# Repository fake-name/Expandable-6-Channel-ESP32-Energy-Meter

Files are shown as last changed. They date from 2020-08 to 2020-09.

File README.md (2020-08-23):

Expandable 6 Channel ESP32 Energy Meter v1.3 Main Board

# CircuitSetup Expandable 6 Channel ESP32 Energy Meter
The Expandable 6 Channel ESP32 Energy Meter can read 6 current channels and 2 voltage channels at a time. Much like our [Split Single Phase Energy Meter](https://circuitsetup.us/index.php/product/split-single-phase-real-time-whole-house-energy-meter-v1-4/), the 6 channel uses current transformers and an AC transformer to measure voltage and power the board(s)/ESP32\. The main board includes a buck converter to power the electronics and ESP32 dev board, which plugs directly into the board. Up to 6 add-on boards can stack on top of the main board to allow you to monitor **up to 42 current channels** in 16-bit resolution, in real time, all at once! This product is currently in the prototype stage, so components may change.

#### **Usage:**

* North American split single phase 120V/240V 60Hz - mains and/or individual circuits
* European single phase 240V 50Hz (must provide [AC-AC transformer](https://learn.openenergymonitor.org/electricity-monitoring/voltage-sensing/different-acac-power-adapters) 9V or 12V with at least 500mA output)
* 3 phase - the meter can be used to measure 3-phase, but power (wattage) will not be calculated correctly. Power can be calculated in software, but the [power factor](https://en.wikipedia.org/wiki/Power_factor) will have to be estimated ((voltage*current)*power_factor))

#### **Features:**

*   Samples 6 current channels & 1 voltage channel (expandable to 2 voltage)
*   Add-on boards (up to 6) can expand the meter up to 42 current channels & 8 voltage channels
*   Uses 2 [Microchip ATM90E32AS](https://www.microchip.com/wwwproducts/en/atm90e32as) - 3 current channels & 1 voltage per IC
*   For each channel the following can also be calculated by the meter:
    *   Active Power
    *   Reactive Power
    *   Apparent Power
    *   Power Factor
    *   Frequency
    *   Temperature
*   Uses standard current transformer clamps to sample current
*   22ohm burden resistors per current channel
*   Includes built-in buck converter to power ESP32 & electronics
*   2 IRQ interrupts, and 1 Warning output
*   Zero crossing outputs
*   Energy Pulse outputs per IC (4 per IC x2)
*   SPI Interface
*   Measurement Error: 0.1%
*   Dynamic Range: 6000:1
*   Current Gain Selection: Up to 4x
*   Voltage Reference Drift Typical (ppm/°C): 6
*   ADC Resolution (bits): 16

#### **What you'll need:**

*   **Current Transformers** (any combination of the following, or any current transformer that does not exceed 1V or 720mA output)
    *   [SCT-006 20A/25mA Micro](https://circuitsetup.us/index.php/product/20a-25ma-micro-current-transformer-yhdc-sct-006-6mm/) (6mm opening - 3.5mm connectors)
    *   [SCT-010 80A/26.6mA Mini](https://circuitsetup.us/index.php/product/80a-26-6ma-mini-current-transformer-yhdc-sct-010-10mm/) (10mm opening - 3.5mm connectors)
    *   [SCT-013-000 100A/50mA](https://circuitsetup.us/index.php/product/100a-50ma-current-transformer-yhdc-sct-013/) (13mm opening - 3.5mm connectors)
    *   [SCT-016 120A/40mA](https://circuitsetup.us/index.php/product/120a-40ma-current-transformer-yhdc-sct-016-with-3-5mm-jack-16mm-opening/) (16mm opening - 3.5mm connectors)
    *   [Magnelab SCT-0750-100](https://amzn.to/2IF8xnY) (screw connectors - must sever burden resistor connection on the back of the board since they have a built in burden resistor).
    *   [SCT-024 200A/100mA](https://www.poweruc.pl/products/split-core-current-transformer-sct024ts-rated-input-400a) (24mm opening - terminal output)
    *   Others can also be used as long as they're rated for the amount of power that you are wanting to measure, and have a current output no more than 720mA.
*   **AC Transformer (NOT DC):** 
    *   North America: [Jameco Reliapro 120V to 9V AC-AC](https://circuitsetup.us/index.php/product/jameco-ac-to-ac-wall-adapter-transformer-9-volt-1000ma-black-straight-2-5mm-female-plug/) or 12v. The positive pin must be 2.5mm (some are 2.1)
    *   Europe: 240V to 9V or 12V AC-AC at least 500mA - [See a list of some recommended transformers here](https://learn.openenergymonitor.org/electricity-monitoring/voltage-sensing/different-acac-power-adapters)
*   **ESP32** (choose one):
    *   [NodeMCU 32s](https://circuitsetup.us/index.php/product/nodemcu-32s-esp32-esp-wroom-32-development-board/)
    *   [Espressif DevKitC](https://amzn.to/2PHvVsg)
    *   [DevKitC-32U](https://www.mouser.com/ProductDetail/Espressif-Systems/ESP32-DevKitC-32U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) if you need better wifi reception (don't forget the antenna)
    *   Anything else with the same pinouts as the above, which are usually 19 pins per side with 3v3 in the upper left & CLK in the lower right
*   **Software** (choose one):
    *   Our custom version of [EmonESP](https://github.com/CircuitSetup/Expandable-6-Channel-ESP32-Energy-Meter/tree/master/Software/EmonESP) and the [ATM90E32](https://github.com/CircuitSetup/ATM90E32) Arduino library
    *   The current dev release of [ESPHome.](https://github.com/esphome/esphome/tree/dev) Details on [integration with Home Assistant are located here.](https://github.com/digiblur/digiNRG_ESPHome) and [here on ESPHome.io](https://next.esphome.io/components/sensor/atm90e32.html). [More examples of configs are located here.](https://github.com/CircuitSetup/Expandable-6-Channel-ESP32-Energy-Meter/tree/master/Software/ESPHome)
    *   Libraries for [CircuitPython](https://github.com/BitKnitting/CircuitSetup_CircuitPython) & [MicroPython](https://github.com/BitKnitting/CircuitSetup_micropython)

### **Setting up the Meter**

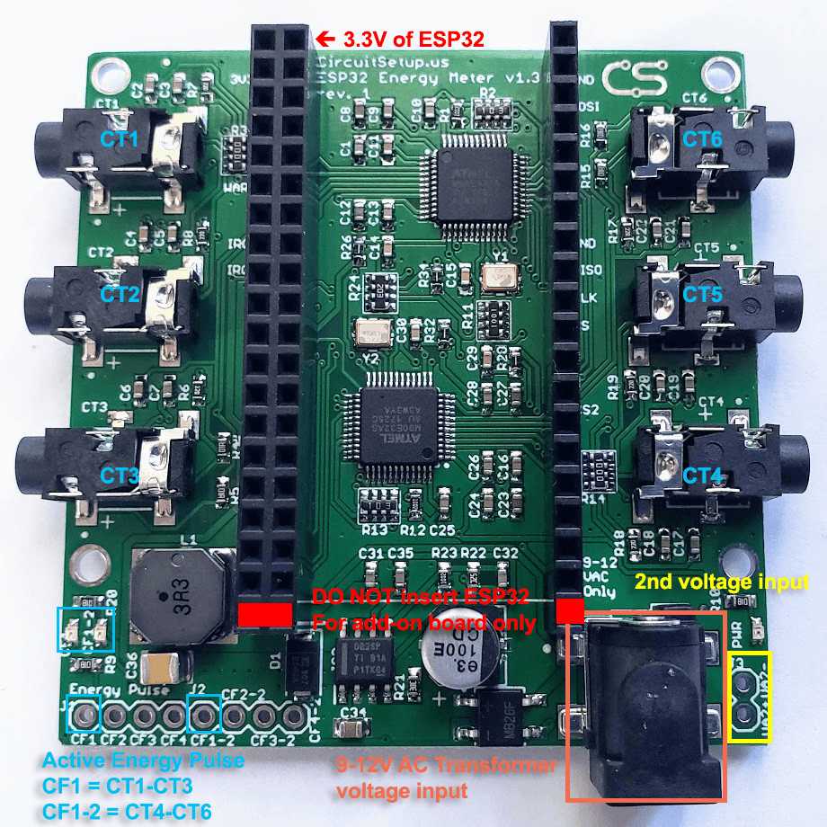
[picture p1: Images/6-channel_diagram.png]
Expandable 6 Channel ESP32 Energy Meter Diagram

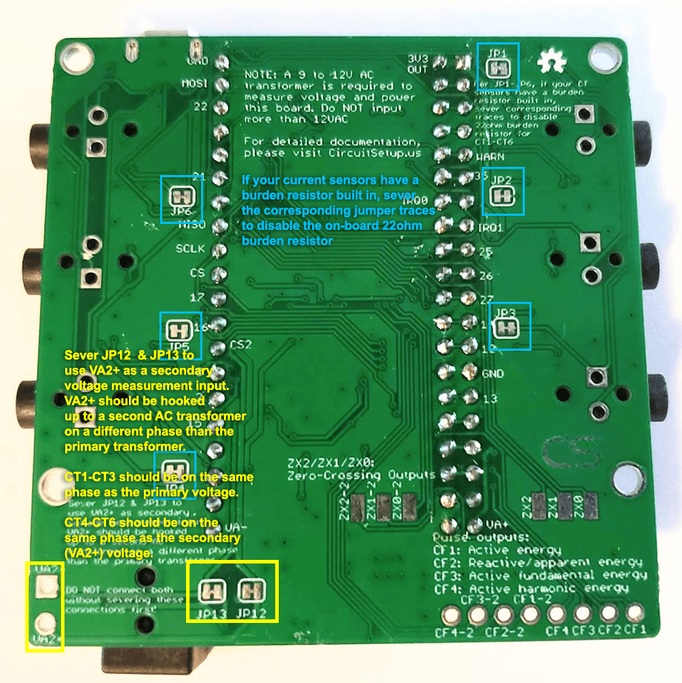
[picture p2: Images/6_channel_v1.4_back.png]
Expandable 6 Channel ESP32 Energy Meter Back Diagram


#### **Plugging in the ESP32**
The Expandable 6 Channel ESP32 Energy Meter is made so that an ESP32 dev board can be plugged directly into the meter. See the list above for compatible ESP32 dev boards. 
**Always insert the ESP32 with the 3V3 pin in the upper left of the meter**. The bottom pins are used to connect the voltage signal (from the power plug) to add-on boards. If the ESP32 is inserted into the bottom pins it will more than likely short the ESP32.

#### **Communicating with the ESP32**
The Expandable 6 Channel ESP32 Energy Meter uses SPI to communicate with the ESP32. Each board uses 2 CS pins. 

The **main board** uses the following SPI pins:
* CLK - 18
* MISO - 19
* MOSI - 23
* CS1 - 5 (CT1-CT3 & Voltage 1)
* CS2 - 4 (CT4-CT6 & Voltage 2)

The version of [EmonESP available here](https://github.com/CircuitSetup/Expandable-6-Channel-ESP32-Energy-Meter/tree/master/Software/EmonESP) has all of these pins set by default. 

For examples of how to set up your config in ESPHome, [see here](https://github.com/CircuitSetup/Expandable-6-Channel-ESP32-Energy-Meter/tree/master/Software/ESPHome) and [here.](https://next.esphome.io/components/sensor/atm90e32.html)

#### **Add-on Boards**
Add-on boards (up to 6) can expand the main energy meter up to 42 current channels & 8 voltage channels. The add-on boards plug directly into the main board as seen here.

The **add-on board** allows the CS pin to be selected based on the jumper settings at the bottom of the board. This is so multiple add-on boards can be used - up to 6 maximum. Do NOT select more than one CS pin per bank. 
The CS pins can be:
  * CT1-CT3 (CS):
    * For v1.3 and under:
      * 0
      * 2 (*make sure that an on board LED is not used for IO2 on the ESP32) 
      * 12 (*will cause ESP32 to not boot if used)
      * 13
      * 14
      * 15
    * For v1.4 and above:
      * 0
      * 27
      * 35 (do not use - it will not work correctly)
      * 13
      * 14
      * 15
    * For v1.4 rev1 and above:
      * 35 is changed to 2 (may prevent the ESP32 from being programmed - disconnect jumper if so)
  * CT4-CT6 (CS2):
    * 16
    * 17
    * 21
    * 22
    * 25
    * 26
    
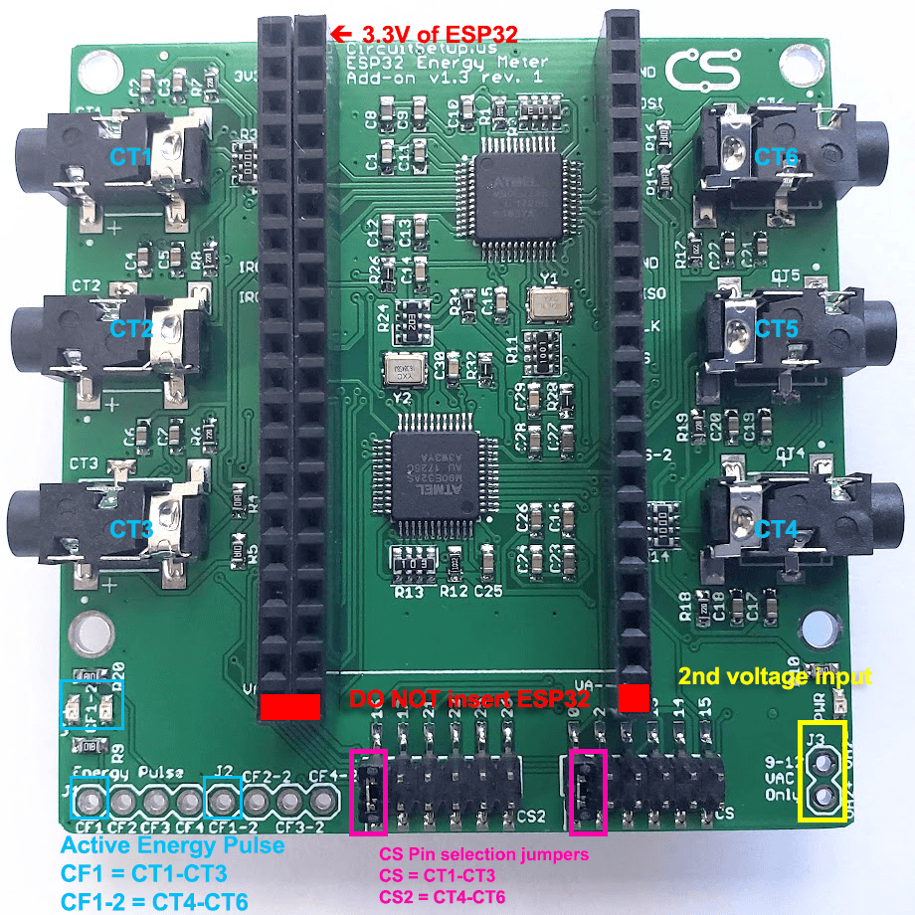
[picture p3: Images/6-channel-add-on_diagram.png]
Expandable 6 Channel ESP32 Energy Meter Add-on Diagram


#### **Calibrating Current Sensors & Voltage (AC Transformer)** 
[See here for the calibration procedure](https://github.com/CircuitSetup/Split-Single-Phase-Energy-Meter#calibration),
[or here for a video](https://youtu.be/BOgy6QbfeZk?t=1261)

##### **Common Calibration Values**
 * Current Transformers:
    * 20A/25mA SCT-006: 11143
    * 30A/1V SCT-013-030: 8650
    * 50A/1V SCT-013-050: 15420
    * 80A/26.6mA SCT-010: 41660
    * 100A/50ma SCT-013-000: 27518
    * 120A/40mA: SCT-016: 41787
    * 200A/100mA SCT-024: 27518
* AC Transformers
    * Jameco 9VAC Transformer 157041: 
       * For meter versions: 
         * v1.3 or greater: 7305
         * v1.2: 42620

#### **Measuring Power & Other Metering Values**
The Expandable 6 Channel ESP32 Energy Meter uses 2 ATM90E32AS ICs. Each IC has 3 voltage channels and 3 current channels. In order for power metering data to be calculated internally, each current channel must have a reference voltage. If the voltage is out of phase with the current, then the current and power will read as negative, affecting the power factor and power calculations. If you have a split single phase or dual phase setup, the solution is to turn around the current transformer on the wire.

v1.1 of the meter used 1 of the voltage channels for each IC. This means that power and metering data would have to be calculated in software, or voltage channels would have to be mapped via changing registers on the IC to get power and metering data from CT2, CT3, CT5, CT6. 

v1.2 & v1.3 have JP8-JP11 on the back of the board, that would allow all voltage channels to be connected together, which would allow power and other metering values to be calculated. Most of v1.3 came soldered together.

v1.4 removed JP8-JP11, and has voltage channels connected internally on the pcb. 

#### **Measuring A Second Voltage**
The holes labelled VA2 next to the power plug on the meter main board, and in the bottom right of the add-on board are for measuring a second voltage. To do this you must:
* Sever (with a knife) JP12 and JP13 on the back of the board for v1.3+, or JP7 for prior versions
* Use a second AC transformer, ideally one identical to the primary
* Plug in the second AC transformer to an outlet on the opposite phase to the primary
* Solder on a pin header, 2.54mm screw connector, or pigtail on to VA2+ & VA2-

When voltage jumpers are severed, the voltage reference for CT4-CT6 will be from VA2. This means that current transformers for CT4-CT6 should be hooked up to circuits that are on the same phase as VA2, and CT1-CT3 should be hooked up to circuits that are in phase with the primary voltage. If a CT is not in phase with the voltage its current and power readings will be negative. If, for example, you have 4 circuits in phase with the primary, and 2 in phase with VA2, you can reverse the current transformer on the wire to put it in phase with the voltage. 

For add-on boards, the primary voltage will come from the main board. The optional secondary voltage measurement (also VA2 pins), will be in phase with CT4-CT6.

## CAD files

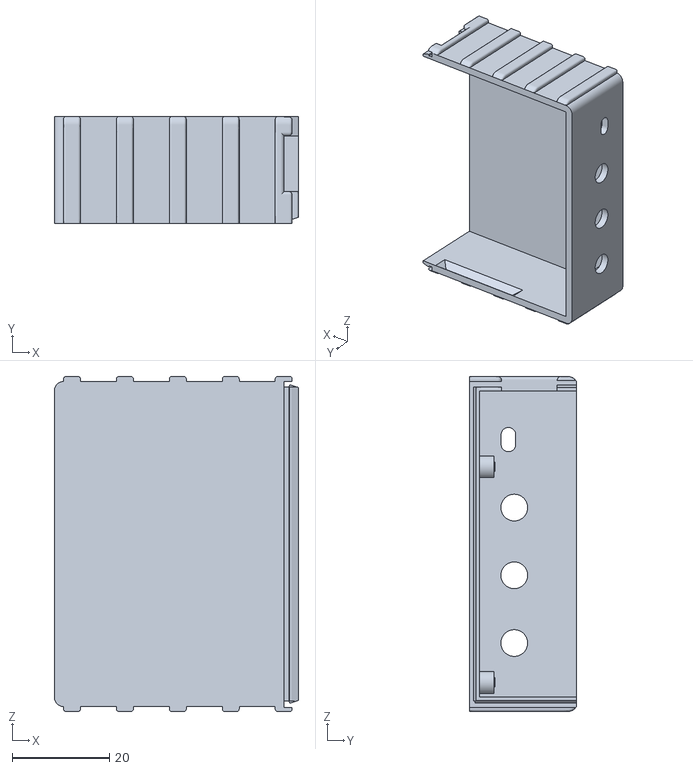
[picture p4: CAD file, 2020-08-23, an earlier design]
Hardware/Eagle-Old/6channel_energy_meter_2piece_case_main_board_large_half.stl
50.3 x 22.0 x 69.0

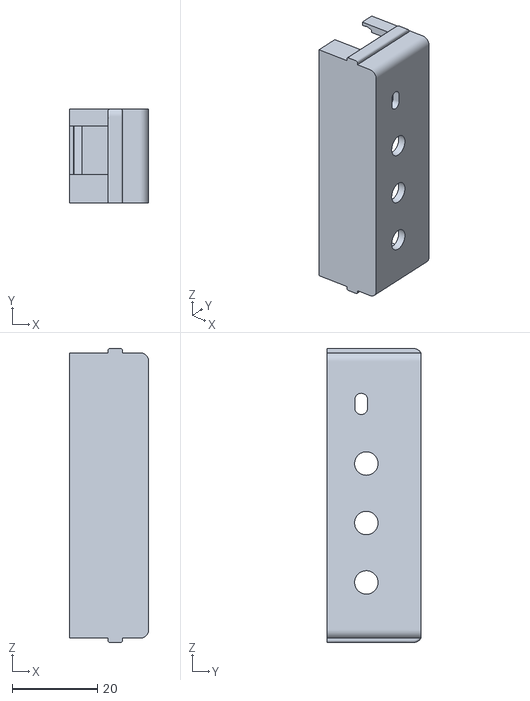
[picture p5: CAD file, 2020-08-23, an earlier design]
Hardware/Eagle-Old/6channel_energy_meter_2piece_case_main_board_small_half.stl
18.6 x 22.0 x 69.0

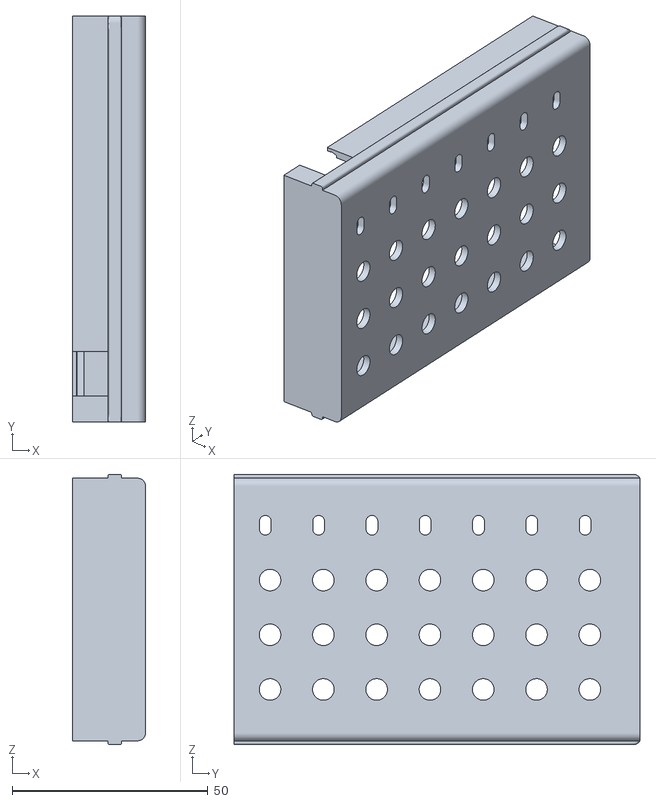
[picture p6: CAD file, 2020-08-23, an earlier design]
Hardware/Eagle-Old/6channel_energy_meter_2piece_case_6-addon_small_half.stl
18.6 x 103.6 x 69.0

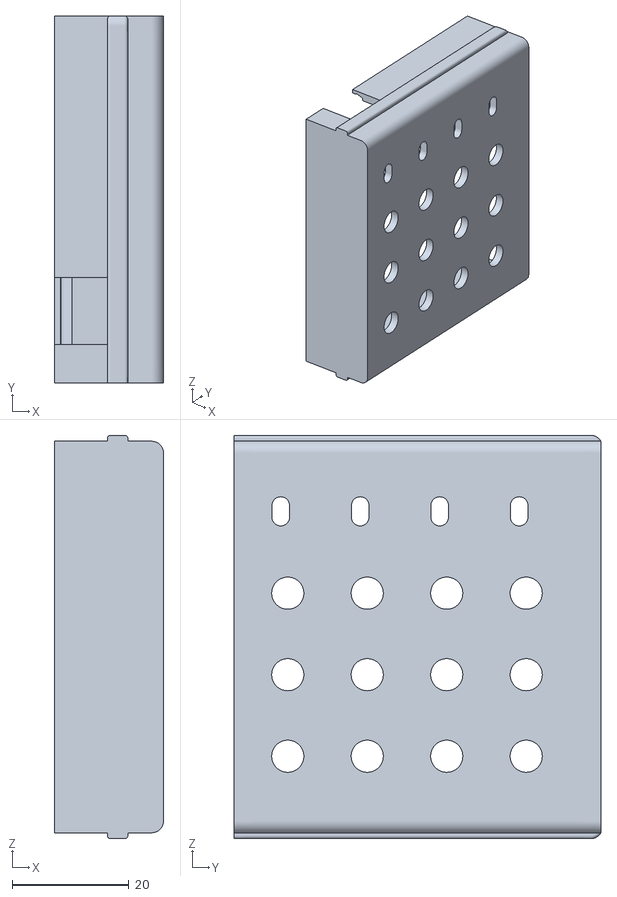
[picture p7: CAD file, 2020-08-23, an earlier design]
Hardware/Eagle-Old/6channel_energy_meter_2piece_case_3-addon_small_half.stl
18.6 x 62.8 x 69.0

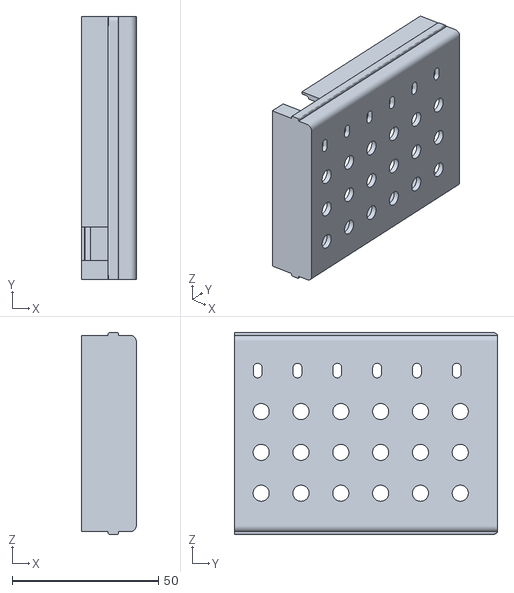
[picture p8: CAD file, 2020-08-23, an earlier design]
Hardware/Eagle-Old/6channel_energy_meter_2piece_case_5-addon_small_half.stl
18.6 x 90.0 x 69.0

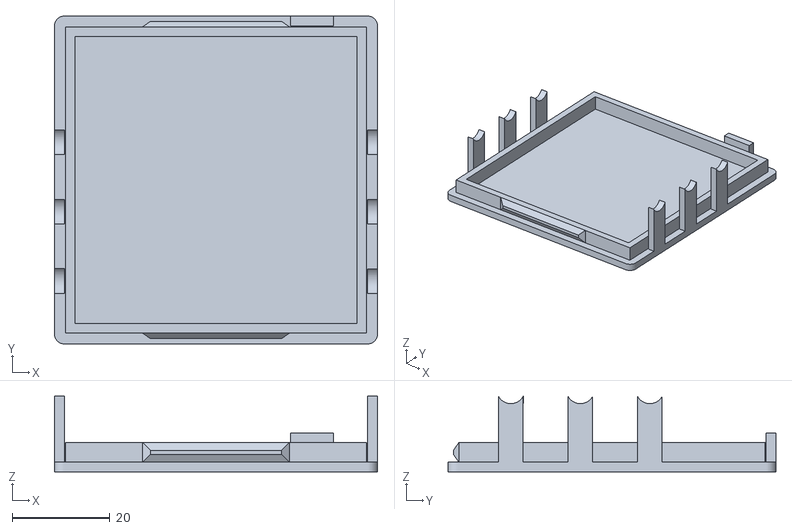
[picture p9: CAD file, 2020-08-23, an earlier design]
Hardware/Eagle-Old/6channel_case_lid.stl
66.0 x 67.0 x 15.5

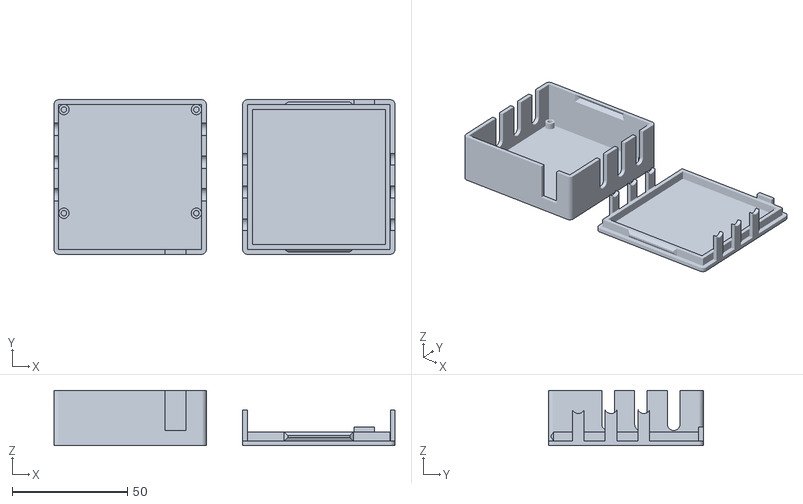
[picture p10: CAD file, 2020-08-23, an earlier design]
Hardware/Eagle-Old/6channel_meter_case.stl
147.7 x 67.0 x 24.0

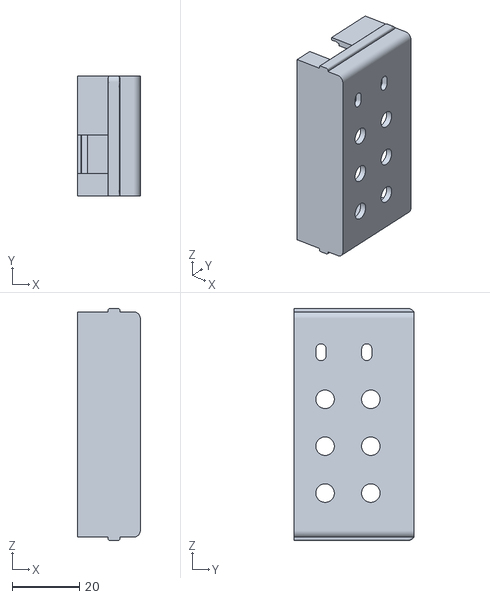
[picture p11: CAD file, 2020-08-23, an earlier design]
Hardware/Eagle-Old/6channel_energy_meter_2piece_case_1-addon_small_half.stl
18.6 x 35.6 x 69.0

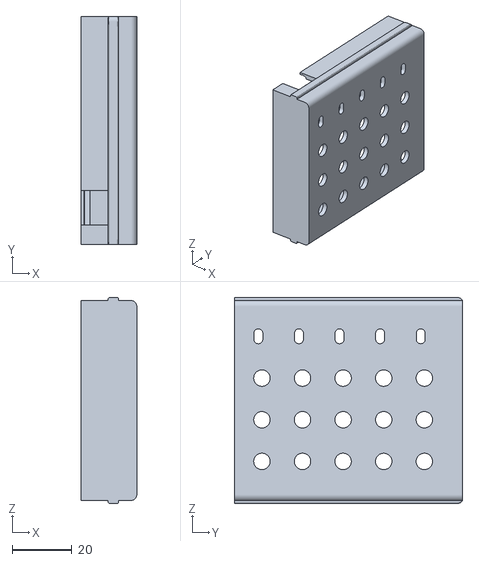
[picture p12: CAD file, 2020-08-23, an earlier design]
Hardware/Eagle-Old/6channel_energy_meter_2piece_case_4-addon_small_half.stl
18.6 x 76.4 x 69.0

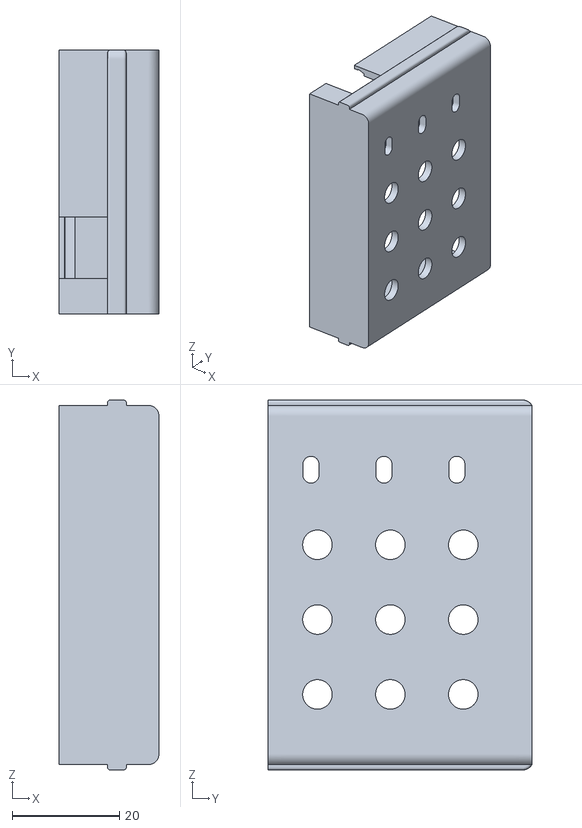
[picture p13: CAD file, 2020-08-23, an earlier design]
Hardware/Eagle-Old/6channel_energy_meter_2piece_case_2-addon_small_half.stl
18.6 x 49.2 x 69.0

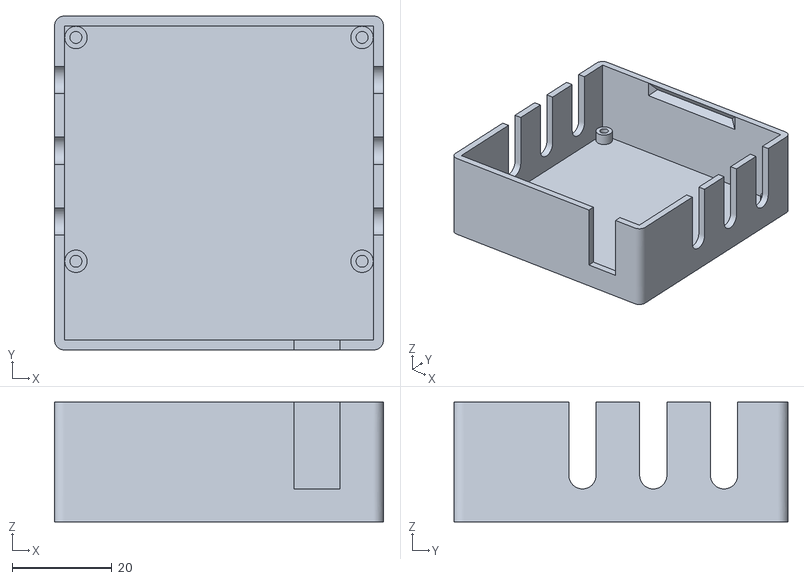
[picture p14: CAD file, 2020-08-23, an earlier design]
Hardware/Eagle-Old/6channel_case.stl
66.0 x 67.0 x 24.0

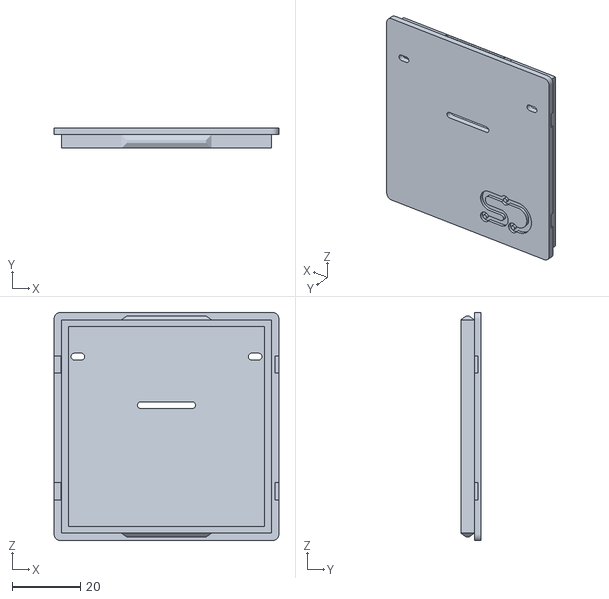
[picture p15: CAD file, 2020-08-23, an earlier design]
Hardware/Eagle-Old/6channel_energy_meter_2piece_case_cover.stl
66.0 x 6.00 x 67.0

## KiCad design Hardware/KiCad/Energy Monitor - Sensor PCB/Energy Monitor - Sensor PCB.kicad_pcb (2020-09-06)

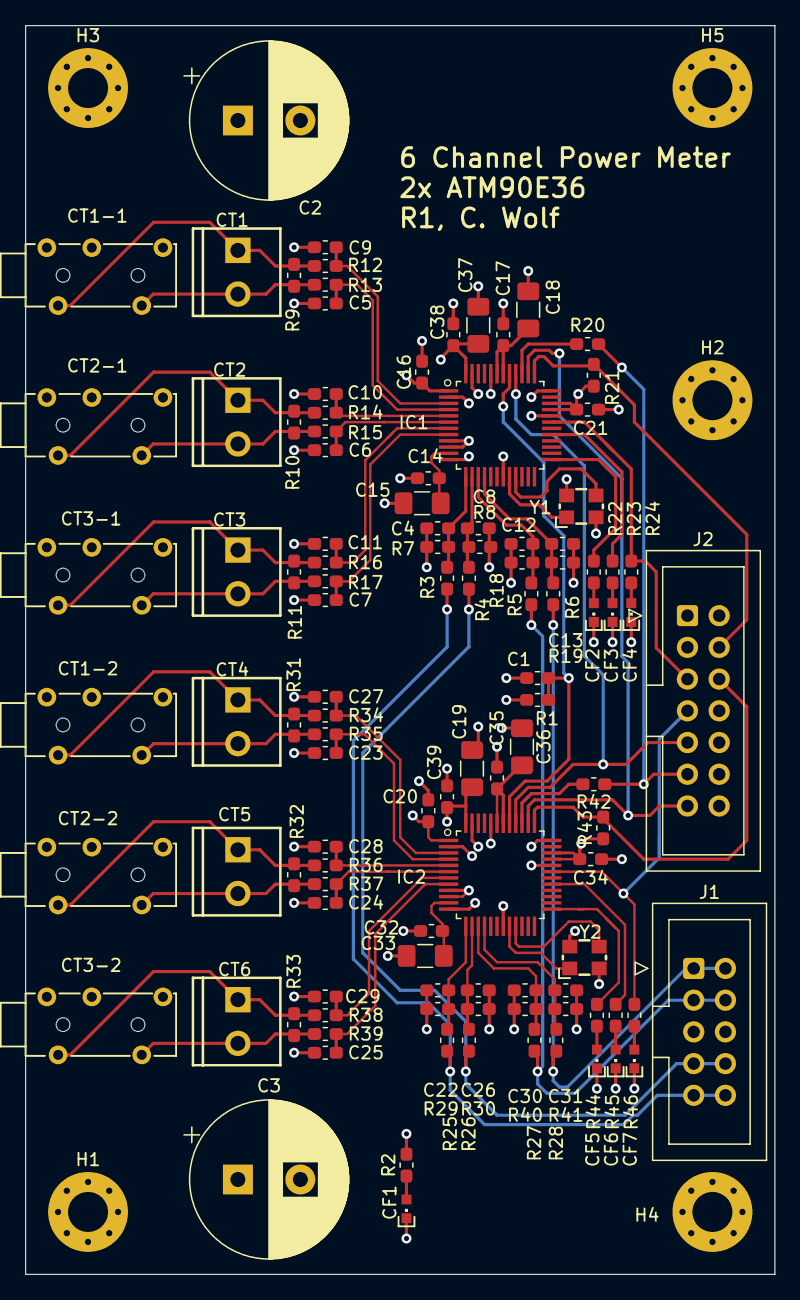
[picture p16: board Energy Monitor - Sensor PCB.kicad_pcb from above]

Board: 4 copper layers, 60.0 x 100.0 mm, 115 parts (0 on the bottom side), 67 nets.

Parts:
C1, C14, C16, C17, C20, C21, C32, C34, C35, C38, C39: 0.1uF; C_0603_1608Metric_Pad1.05x0.95mm_HandSolder
C2, C3: CP1; CP_Radial_D12.5mm_P5.00mm
C4, C8, C12, C13, C22, C26, C30, C31: 18nF; C_0603_1608Metric_Pad1.05x0.95mm_HandSolder
C5, C6, C7, C9, C10, C11, C23, C24, C25, C27, C28, C29: 0.33uF; C_0603_1608Metric_Pad1.05x0.95mm_HandSolder
C15, C18, C19, C33, C36, C37: 10uF; C_1206_3216Metric_Pad1.42x1.75mm_HandSolder
CF1, CF2, CF3, CF4, CF5, CF6, CF7: BLU; CHIPLED_0603
CT1, CT2, CT3, CT4, CT5, CT6: CONN_023.5MM; SCREWTERMINAL-3.5MM-2
CT1-1, CT1-2, CT2-1, CT2-2, CT3-1, CT3-2: SJ2-35813B-SMT-TR; PJ-3270
H1, H2, H3, H4, H5: MountingHole; MountingHole_3.2mm_M3_Pad_Via
IC1, IC2: ATM90E36; QFP50P900X900X120-48
J1: Conn_02x05_Odd_Even; IDC-Header_2x05_P2.54mm_Vertical
J2: Conn_02x07_Odd_Even; IDC-Header_2x07_P2.54mm_Vertical
R1, R21, R43: 10K; R_0603_1608Metric_Pad1.05x0.95mm_HandSolder
R2: 1k; R_0603_1608Metric_Pad1.05x0.95mm_HandSolder
R3, R4, R5, R6, R25, R26, R27, R28: 20K; R_0603_1608Metric_Pad1.05x0.95mm_HandSolder
R7, R8, R18, R19, R22, R23, R24, R29, R30, R40, R41, R44, R45, R46: 1K; R_0603_1608Metric_Pad1.05x0.95mm_HandSolder
R9, R10, R11, R31, R32, R33: 22R; R_0603_1608Metric_Pad1.05x0.95mm_HandSolder
R12, R13, R14, R15, R16, R17, R20, R34, R35, R36, R37, R38, R39, R42: 100R; R_0603_1608Metric_Pad1.05x0.95mm_HandSolder
Y1, Y2: 16.384MHz; CRYSTAL-SMD-3.2X2.5MM

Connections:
+3V3: C2.1, C3.1, C16.1, C19.1, C20.1, C21.1, C34.1, C37.1, C38.1, C39.1, IC1.1, IC1.33, IC1.34, IC1.48, IC2.1, IC2.33, IC2.34, IC2.48, J2.1, J2.3, R1.1, R2.2, R21.1, R43.1
/meter_1/1.8VDD: C17.1, C18.1, IC1.42, IC1.43
/meter_1/I1N: C5.1, IC1.4, R13.2
/meter_1/I1P: C9.1, IC1.3, R12.2
/meter_1/I2N: C6.1, IC1.6, R15.2
/meter_1/I2P: C10.1, IC1.5, R14.2
/meter_1/I3N: C7.1, IC1.8, R17.2
/meter_1/I3P: C11.1, IC1.7, R16.2
/meter_1/IRQ1: IC1.31, J2.5, R24.1
/meter_1/SCLK: IC1.38, IC2.38, J2.13
/meter_1/SDI: IC1.40, IC2.40, J2.9
/meter_1/SDO: J2.11, R20.1, R42.1
/meter_1/V1N: J1.7, J1.8, R4.2, R26.2
/meter_1/V1P: J1.9, J1.10, R3.2, R25.2
/meter_1/V2N: J1.1, J1.2, R6.2, R28.2
/meter_1/V2P: J1.3, J1.4, R5.2, R27.2
/meter_1/~CS: IC1.37, J2.4, R21.2
/meter_1/~RESET: C1.1, IC1.41, IC2.41, R1.2
/meter_2/1.8VDD: C35.1, C36.1, IC2.42, IC2.43
/meter_2/I1N: C23.1, IC2.4, R35.2
/meter_2/I1P: C27.1, IC2.3, R34.2
/meter_2/I2N: C24.1, IC2.6, R37.2
/meter_2/I2P: C28.1, IC2.5, R36.2
/meter_2/I3N: C25.1, IC2.8, R39.2
/meter_2/I3P: C29.1, IC2.7, R38.2
/meter_2/IRQ1: IC2.31, J2.7, R46.1
/meter_2/~CS: IC2.37, J2.6, R43.2
GND: C1.2, C2.2, C3.2, C4.2, C5.2, C6.2, C7.2, C8.2, C9.2, C10.2, C11.2, C12.2, C13.2, C14.2, C15.2, C16.2, C17.2, C18.2, C19.2, C20.2, C21.2, C22.2, C23.2, C24.2, C25.2, C26.2, C27.2, C28.2, C29.2, C30.2, C31.2, C32.2, C33.2, C34.2, C35.2, C36.2, C37.2, C38.2, C39.2, CF1.C, CF2.C, CF3.C, CF4.C, CF5.C, CF6.C, CF7.C, IC1.2, IC1.9, IC1.10, IC1.12, IC1.19, IC1.32, IC1.36, IC1.44, IC1.47, IC2.2, IC2.9, IC2.10, IC2.12, IC2.19, IC2.32, IC2.36, IC2.44, IC2.47, J2.8, J2.10, J2.12, J2.14, R7.1, R8.1, R18.1, R19.1, R29.1, R30.1, R40.1, R41.1, Y1.2, Y1.4, Y2.2, Y2.4
unnamed: C4.1, IC1.13, R3.1, R7.2
unnamed: C8.1, IC1.14, R4.1, R8.2
unnamed: C12.1, IC1.15, R5.1, R18.2
unnamed: C13.1, IC1.16, R6.1, R19.2
unnamed: C14.1, C15.1, IC1.11
unnamed: C22.1, IC2.13, R25.1, R29.2
unnamed: C26.1, IC2.14, R26.1, R30.2
unnamed: C30.1, IC2.15, R27.1, R40.2
unnamed: C31.1, IC2.16, R28.1, R41.2
unnamed: C32.1, C33.1, IC2.11
unnamed: CF1.A, R2.1
unnamed: CF2.A, R22.2
unnamed: CF3.A, R23.2
unnamed: CF4.A, R24.2
unnamed: CF5.A, R44.2
unnamed: CF6.A, R45.2
unnamed: CF7.A, R46.2
unnamed: CT1.2, CT1-1.2, R9.1, R13.1
unnamed: CT1.1, CT1-1.3, R9.2, R12.1
unnamed: CT1-2.2, CT4.2, R31.1, R35.1
unnamed: CT1-2.3, CT4.1, R31.2, R34.1
unnamed: CT2.2, CT2-1.2, R10.1, R15.1
unnamed: CT2.1, CT2-1.3, R10.2, R14.1
unnamed: CT2-2.2, CT5.2, R32.1, R37.1
unnamed: CT2-2.3, CT5.1, R32.2, R36.1
unnamed: CT3.2, CT3-1.2, R11.1, R17.1
unnamed: CT3.1, CT3-1.3, R11.2, R16.1
unnamed: CT3-2.2, CT6.2, R33.1, R39.1
unnamed: CT3-2.3, CT6.1, R33.2, R38.1
unnamed: IC1.20, Y1.1
unnamed: IC1.21, Y1.3
unnamed: IC1.25, R22.1
unnamed: IC1.29, R23.1
unnamed: IC1.39, R20.2
unnamed: IC2.20, Y2.1
unnamed: IC2.21, Y2.3
unnamed: IC2.25, R44.1
unnamed: IC2.29, R45.1
unnamed: IC2.39, R42.2

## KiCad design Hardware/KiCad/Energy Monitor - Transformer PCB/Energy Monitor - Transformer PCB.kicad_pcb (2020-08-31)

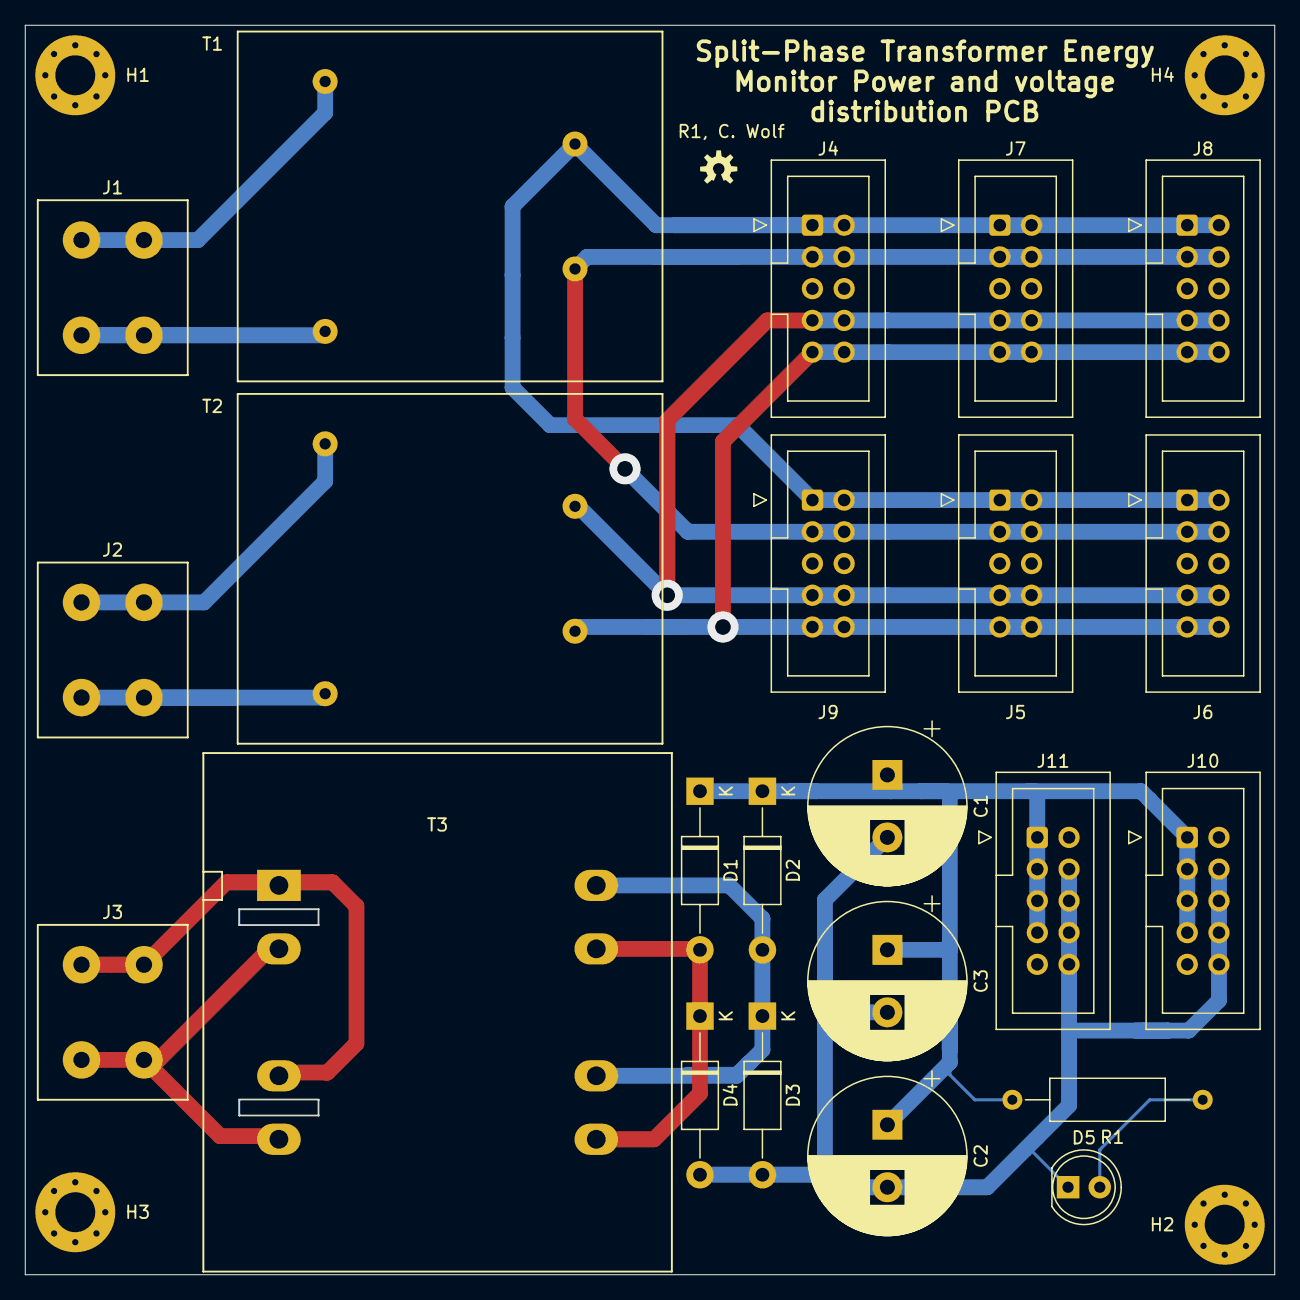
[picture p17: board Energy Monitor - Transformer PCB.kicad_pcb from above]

Board: 2 copper layers, 100.0 x 100.0 mm, 27 parts (0 on the bottom side), 15 nets.

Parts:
C1, C2, C3: CP1; CP_Radial_D12.5mm_P5.00mm
D1, D2, D3, D4: D; D_DO-41_SOD81_P12.70mm_Horizontal
D5: LED; LED_D5.0mm_Clear
H1, H2, H3, H4: MountingHole; MountingHole_3.2mm_M3_Pad_Via
J1, J2, J3: Conn_01x02; WE 691411410002 - 2 Pin Wire-To-Board Terminal Block
J4, J5, J6, J7, J8, J9, J10, J11: Conn_02x05_Odd_Even; IDC-Header_2x05_P2.54mm_Vertical
R1: 1K; R_Axial_DIN0309_L9.0mm_D3.2mm_P15.24mm_Horizontal
T1, T2: EI30-15.5; EI30-15.5-TH
T3: AHI050; AHI050-TH

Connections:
+9V: C1.1, C2.1, C3.1, D1.1, D2.1, J10.1, J10.3, J10.5, J10.7, J11.1, J11.3, J11.5, J11.7, R1.1
GND: C1.2, C2.2, C3.2, D3.2, D4.2, D5.1, J10.4, J10.6, J10.8, J10.10, J11.4, J11.6, J11.8, J11.10
unnamed: D1.2, D4.1, T3.6, T3.8
unnamed: D2.2, D3.1, T3.5, T3.7
unnamed: D5.2, R1.2
unnamed: J1.1, T1.1
unnamed: J1.2, T1.5
unnamed: J2.1, T2.1
unnamed: J2.2, T2.5
unnamed: J3.1, T3.1, T3.3
unnamed: J3.2, T3.2, T3.4
unnamed: J4.1, J4.2, J5.1, J5.2, J6.1, J6.2, J7.1, J7.2, J8.1, J8.2, J9.1, J9.2, T1.9
unnamed: J4.3, J4.4, J5.3, J5.4, J6.3, J6.4, J7.3, J7.4, J8.3, J8.4, J9.3, J9.4, T1.7
unnamed: J4.7, J4.8, J5.7, J5.8, J6.7, J6.8, J7.7, J7.8, J8.7, J8.8, J9.7, J9.8, T2.9
unnamed: J4.9, J4.10, J5.9, J5.10, J6.9, J6.10, J7.9, J7.10, J8.9, J8.10, J9.9, J9.10, T2.7

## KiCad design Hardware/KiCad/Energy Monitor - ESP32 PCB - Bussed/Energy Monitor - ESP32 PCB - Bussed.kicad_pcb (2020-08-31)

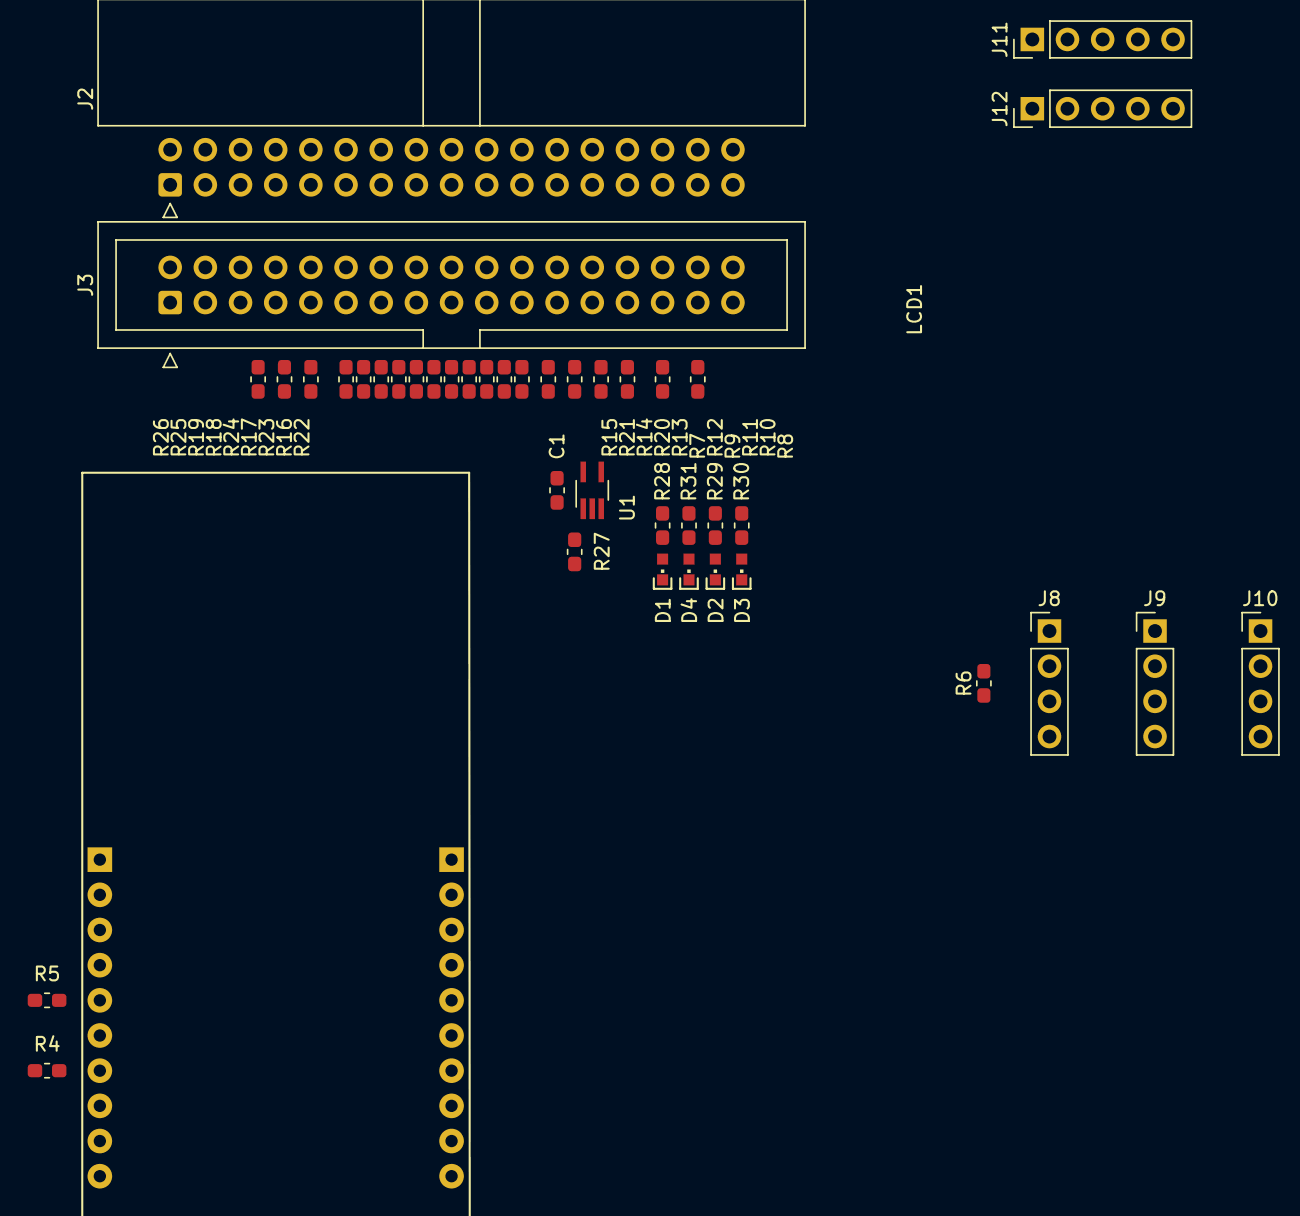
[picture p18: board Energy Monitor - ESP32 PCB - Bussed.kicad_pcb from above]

Board: 4 copper layers, 43 parts (0 on the bottom side), 32 nets, no tracks yet.

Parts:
C1: 0.1 uF; C_0603_1608Metric_Pad1.05x0.95mm_HandSolder
D1, D2, D3, D4: LED; CHIPLED_0603
J2: Conn_02x17_Odd_Even; IDC-Header_2x17_P2.54mm_Horizontal
J3: Conn_02x17_Odd_Even; IDC-Header_2x17_P2.54mm_Vertical
J8, J9, J10: Conn_01x04; PinHeader_1x04_P2.54mm_Vertical
J11, J12: Conn_01x05; PinHeader_1x05_P2.54mm_Vertical
LCD1: 0.96; 12864-DISP-I2C
R4, R5: 2.2K; R_0603_1608Metric_Pad1.05x0.95mm_HandSolder
R6, R27: 10K; R_0603_1608Metric_Pad1.05x0.95mm_HandSolder
R7, R9, R12: 660R; R_0603_1608Metric_Pad1.05x0.95mm_HandSolder
R8, R10, R11: 49.9K; R_0603_1608Metric_Pad1.05x0.95mm_HandSolder
R13, R14, R15, R16, R17, R18, R19, R20, R21, R22, R23, R24, R25, R26: 100R; R_0603_1608Metric_Pad1.05x0.95mm_HandSolder
R28, R29, R30, R31: 1K; R_0603_1608Metric_Pad1.05x0.95mm_HandSolder
U1: 74LVC1G04; SOT-353_SC-70-5_Handsoldering
U2: ESP32-POE Module; ESP32-POE

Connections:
+3V3: C1.1, J2.1, J2.3, J2.5, J2.7, J3.1, J3.3, J3.5, J3.7, J8.3, J9.3, J10.3, J11.2, J12.2, R4.1, R5.1, R6.1, R7.1, R9.1, R28.1, R31.1, U1.5
+5V: J2.2, J2.4, J2.6, J3.2, J3.4, J3.6, J8.4, J9.4, J10.4, J11.1, J12.1, R30.1, U2.1
/ESP1/IRQ_1: J2.23, J3.23, R7.2
/ESP1/IRQ_2: J2.25, J3.25, R9.2
/ESP1/MISO: J2.29, J3.29, R10.1, U2.13
/ESP1/MOSI: J2.27, J3.27, R11.1, U2.18
/ESP1/RESET: J2.22, J3.22, R12.1
/ESP1/SCL: J11.3, J12.3, R5.2, U2.5
/ESP1/SCLK: J2.31, J3.31, R8.1, U2.19
/ESP1/SDA: J11.4, J12.4, R4.2, U2.7
/ESP1/~CS_1: J2.8, J3.8, R26.2
/ESP1/~CS_2: J2.9, J3.9, R19.2
/ESP1/~CS_3: J2.10, J3.10, R25.2
/ESP1/~CS_4: J2.11, J3.11, R18.2
/ESP1/~CS_5: J2.12, J3.12, R24.2
/ESP1/~CS_6: J2.13, J3.13, R17.2
/ESP1/~CS_7: J2.14, J3.14, R23.2
/ESP1/~CS_8: J2.15, J3.15, R16.2
/ESP1/~CS_9: J2.16, J3.16, R22.2
/ESP1/~CS_10: J2.17, J3.17, R15.2
/ESP1/~CS_11: J2.18, J3.18, R21.2
/ESP1/~CS_12: J2.19, J3.19, R14.2
/ESP1/~CS_13: J2.20, J3.20, R20.2
/ESP1/~CS_14: J2.21, J3.21, R13.2
GND: C1.2, D2.1, D3.1, D4.1, J2.24, J2.26, J2.28, J2.30, J2.32, J2.33, J2.34, J3.24, J3.26, J3.28, J3.30, J3.32, J3.33, J3.34, J8.1, J9.1, J10.1, J11.5, J12.5, R8.2, R10.2, R11.2, R27.2, U1.3, U2.3
unnamed: D1.2, R28.2
unnamed: D2.2, R29.2
unnamed: D3.2, R30.2
unnamed: D4.2, R31.2
unnamed: J8.2, J9.2, J10.2, R6.2, U2.15
unnamed: R12.2, R29.1, U1.4
unnamed: R27.1, U1.2

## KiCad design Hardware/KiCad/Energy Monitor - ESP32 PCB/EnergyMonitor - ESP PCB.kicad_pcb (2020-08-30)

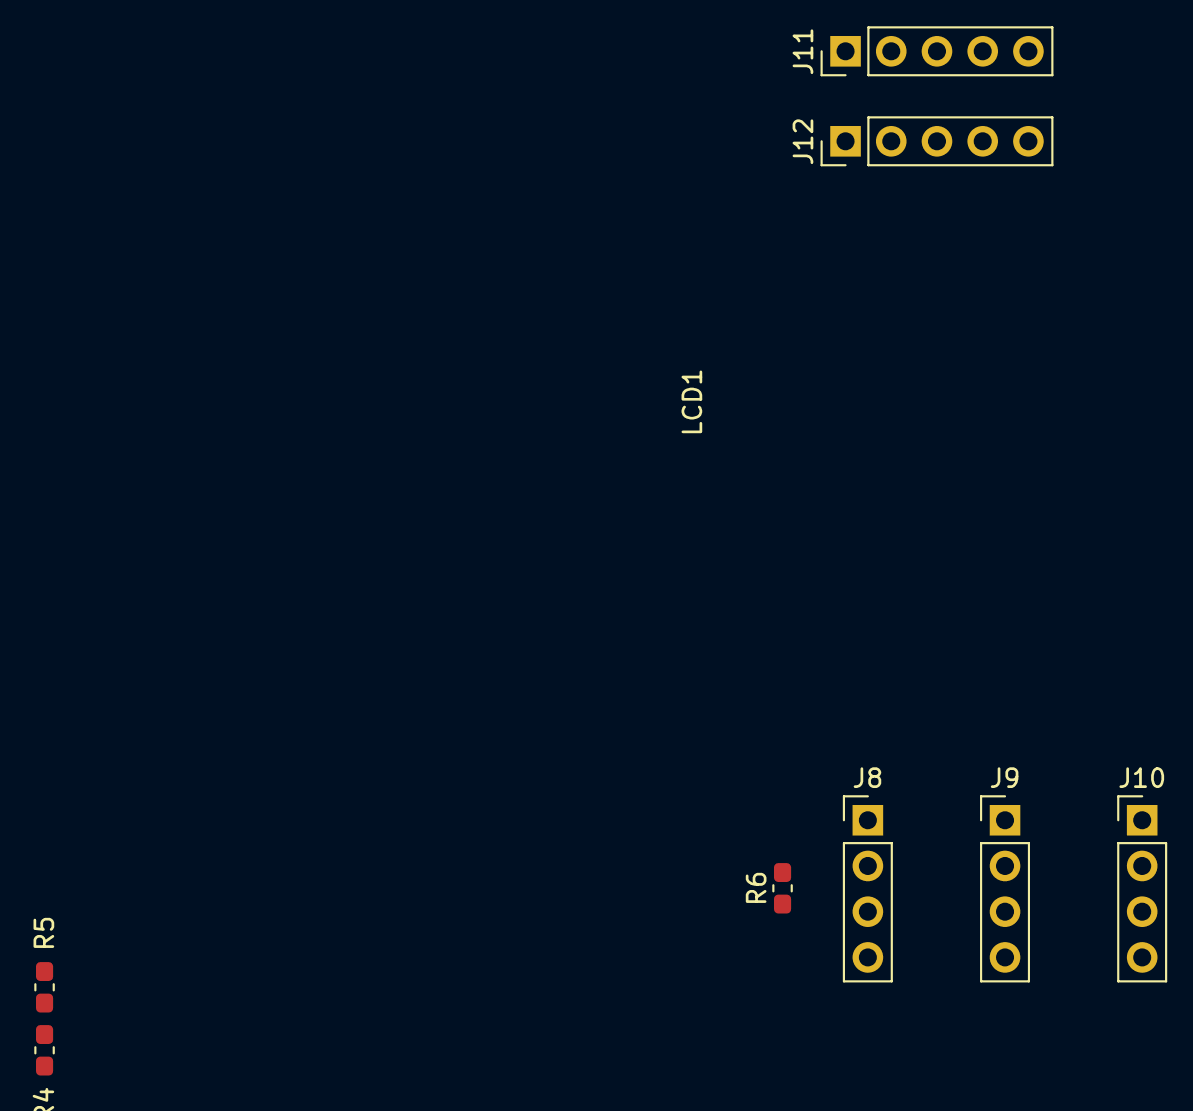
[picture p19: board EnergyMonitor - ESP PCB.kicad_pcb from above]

Board: 4 copper layers, 9 parts (0 on the bottom side), 6 nets, no tracks yet.

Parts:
J8, J9, J10: Conn_01x04; PinHeader_1x04_P2.54mm_Vertical
J11, J12: Conn_01x05; PinHeader_1x05_P2.54mm_Vertical
LCD1: 0.96; 12864-DISP-I2C
R4, R5: 2.2K; R_0603_1608Metric_Pad1.05x0.95mm_HandSolder
R6: 10K; R_0603_1608Metric_Pad1.05x0.95mm_HandSolder

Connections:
+3V3: J8.3, J9.3, J10.3, J11.2, J12.2, R4.1, R5.1, R6.1
+5V: J8.4, J9.4, J10.4, J11.1, J12.1
GND: J8.1, J9.1, J10.1, J11.5, J12.5
unnamed: J8.2, J9.2, J10.2, R6.2
unnamed: J11.3, J12.3, R5.2
unnamed: J11.4, J12.4, R4.2

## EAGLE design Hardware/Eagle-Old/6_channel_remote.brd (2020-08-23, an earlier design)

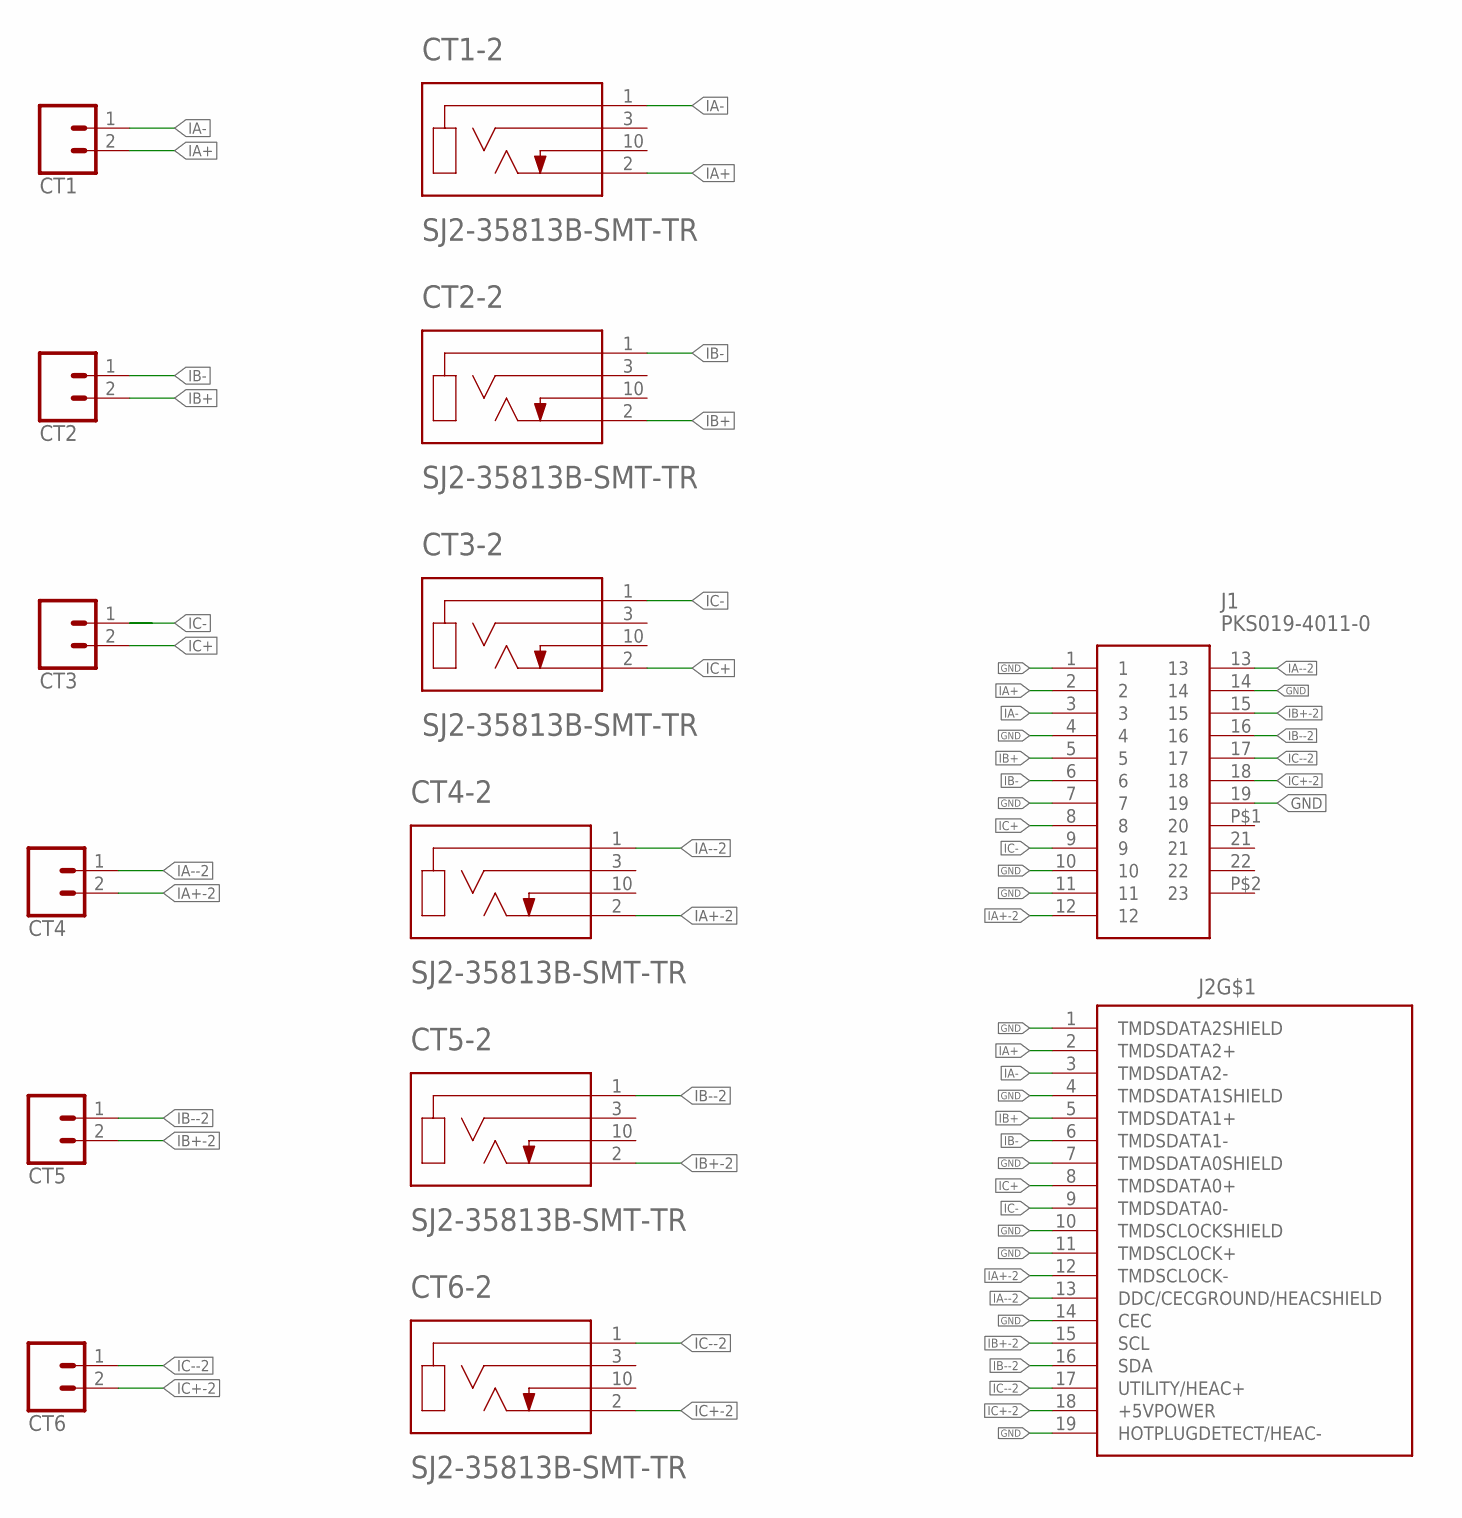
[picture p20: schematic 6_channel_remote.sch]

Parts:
CT1, CT2, CT3, CT4, CT5, CT6: CONN_023.5MM; SCREWTERMINAL-3.5MM-2
CT1-2, CT2-2, CT3-2, CT4-2, CT5-2, CT6-2: SJ2-35813B-SMT-TR; CUI_SJ2-35813B-SMT-TR
J1: PKS019-4011-0; PKS01940110
J2: 685119136923

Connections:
GND: J1.1, J1.4, J1.7, J1.10, J1.11, J1.14, J1.19, J2.1 (TMDSDATA2SHIELD), J2.4 (TMDSDATA1SHIELD), J2.7 (TMDSDATA0SHIELD), J2.10 (TMDSCLOCKSHIELD), J2.11 (TMDSCLOCK+), J2.14 (CEC), J2.19 (HOTPLUGDETECT/HEAC-)
IA+: CT1.2, CT1-2.2 (TIP), J1.2, J2.2 (TMDSDATA2+)
IA+-2: CT4.2, CT4-2.2 (TIP), J1.12, J2.12 (TMDSCLOCK-)
IA-: CT1.1, CT1-2.1 (SLEEVE), J1.3, J2.3 (TMDSDATA2-)
IA--2: CT4.1, CT4-2.1 (SLEEVE), J1.13, J2.13 (DDC/CECGROUND/HEACSHIELD)
IB+: CT2.2, CT2-2.2 (TIP), J1.5, J2.5 (TMDSDATA1+)
IB+-2: CT5.2, CT5-2.2 (TIP), J1.15, J2.15 (SCL)
IB-: CT2.1, CT2-2.1 (SLEEVE), J1.6, J2.6 (TMDSDATA1-)
IB--2: CT5.1, CT5-2.1 (SLEEVE), J1.16, J2.16 (SDA)
IC+: CT3.2, CT3-2.2 (TIP), J1.8, J2.8 (TMDSDATA0+)
IC+-2: CT6.2, CT6-2.2 (TIP), J1.18, J2.18 (+5VPOWER)
IC-: CT3.1, CT3-2.1 (SLEEVE), J1.9, J2.9 (TMDSDATA0-)
IC--2: CT6.1, CT6-2.1 (SLEEVE), J1.17, J2.17 (UTILITY/HEAC+)

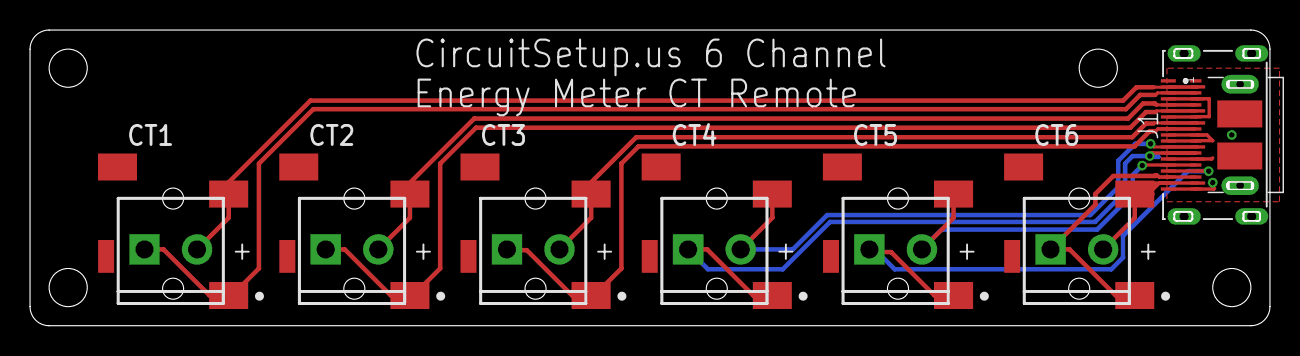
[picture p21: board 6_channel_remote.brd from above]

Board: 2 copper layers, 82.5 x 19.7 mm, 14 parts (0 on the bottom side), 13 nets.

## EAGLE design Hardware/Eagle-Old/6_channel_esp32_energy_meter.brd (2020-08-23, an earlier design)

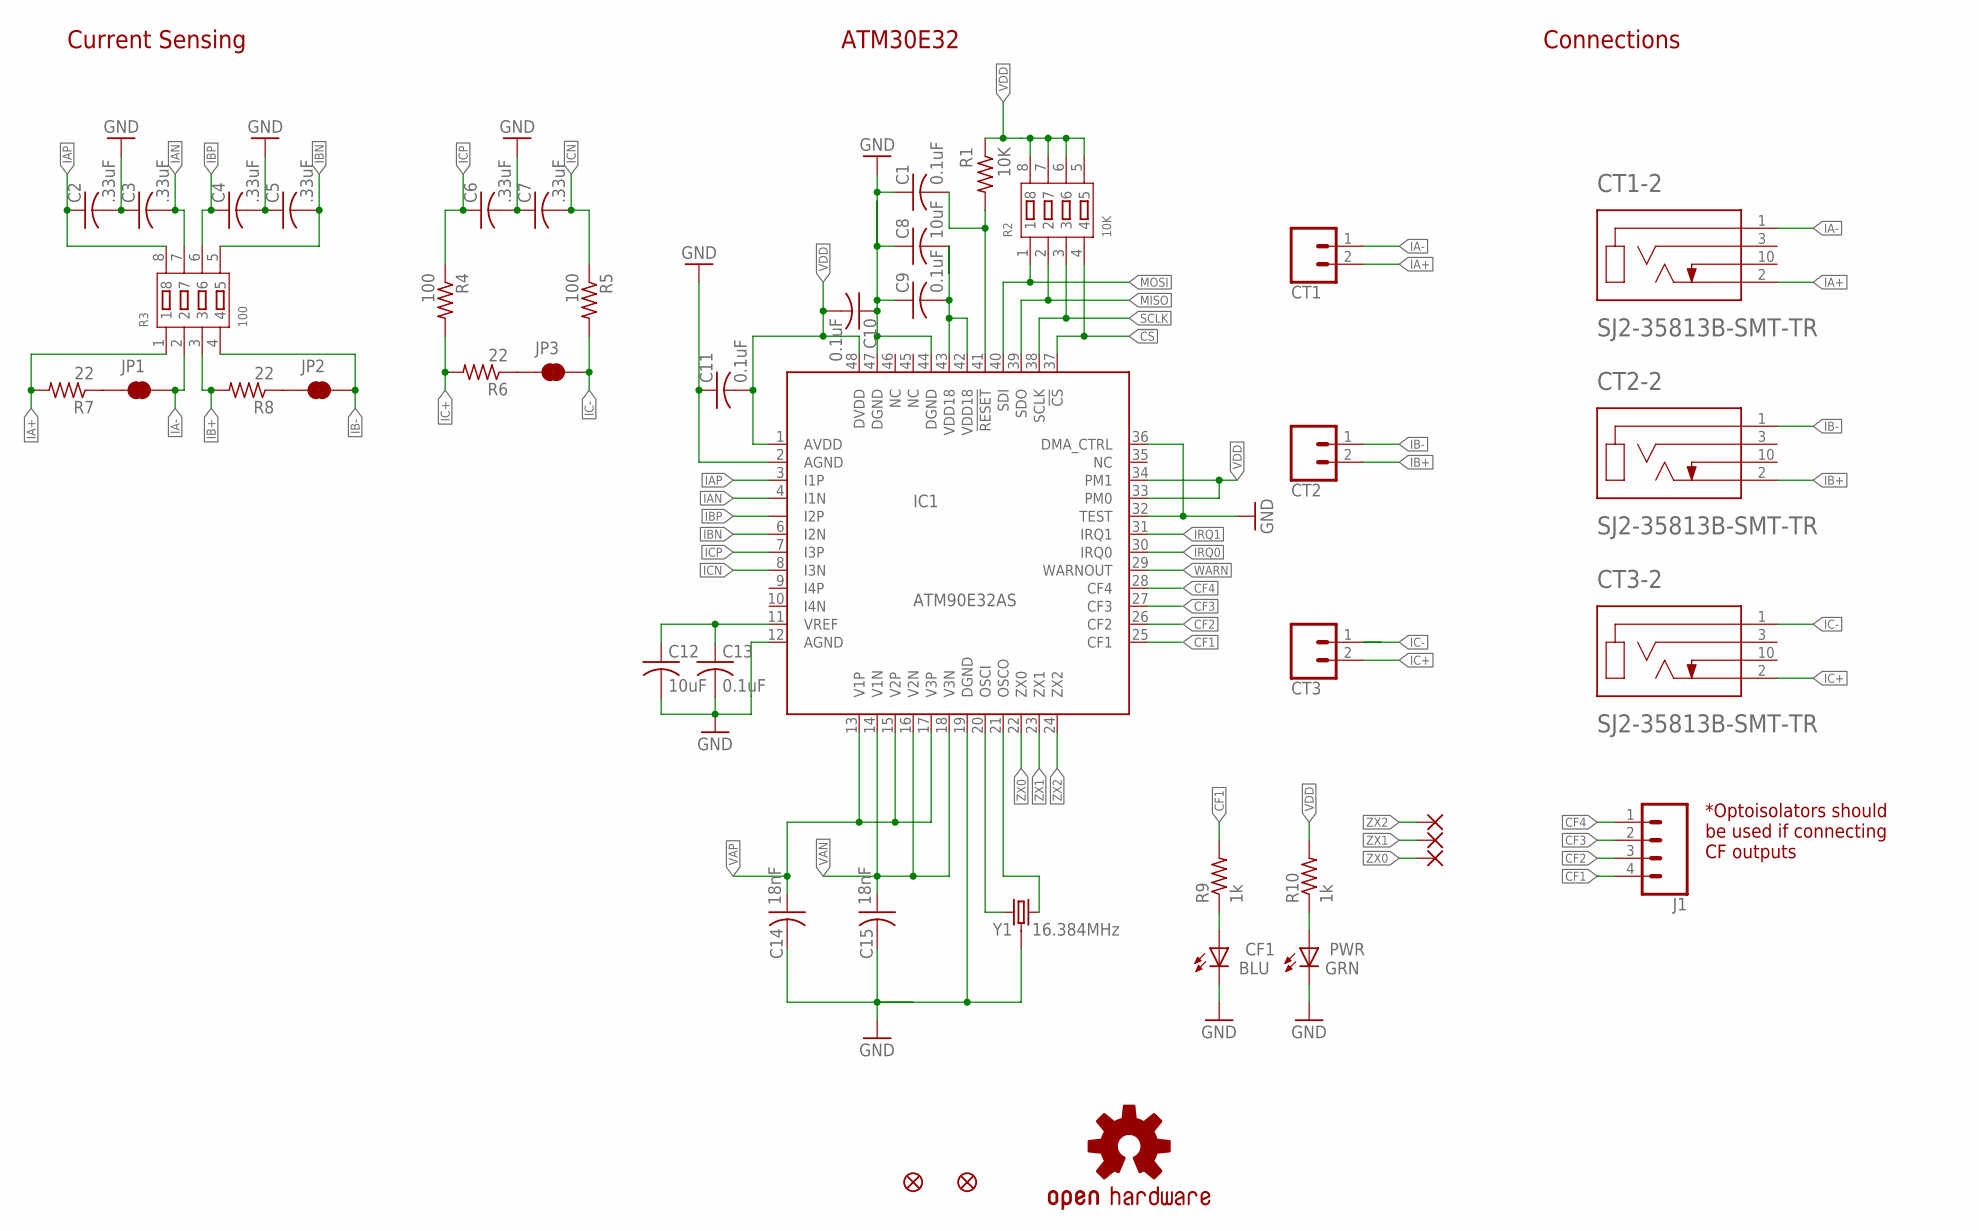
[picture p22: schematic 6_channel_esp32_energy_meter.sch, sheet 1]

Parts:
C1, C9, C10, C11, C13: 0.1uF; C0603
C2, C3, C4, C5, C6, C7: .33uF; C0603
C8, C12: 10uF; C0603
C14, C15: 18nF; C0603
CF1: BLU; CHIPLED_0603
CT1, CT2, CT3: CONN_023.5MM; SCREWTERMINAL-3.5MM-2
CT1-2, CT2-2, CT3-2: SJ2-35813B-SMT-TR; CUI_SJ2-35813B-SMT-TR
FD1, FD2: FIDUCIALUFIDUCIAL; FIDUCIAL-MICRO
IC1: ATM90E32AS; QFP50P900X900X120-48
J1: CONN_04; 1X04
JP1, JP2, JP3: JUMPER-SMT_2_NC_TRACE_SILK; SMT-JUMPER_2_NC_TRACE_SILK
LOGO1: OSHW-LOGOS; OSHW-LOGO-S
PWR: GRN; CHIPLED_0603
R1: 10K; R0603
R2: 10K; RA1206-8
R3: 100; RA1206-8
R4, R5: 100; R0603
R6, R7, R8: 22; R0603
R9, R10: 1k; R0603
Y1: 16.384MHz; CRYSTAL-SMD-3.2X2.5MM
ZX0, ZX1, ZX2: WIREPADSMD1,27-254; SMD1,27-2,54

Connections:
!CS: IC1.37 (!CS), R2.4; also elsewhere on the board
!RESET: C1.2, IC1.41 (!RESET), R1.2
CF1: IC1.25 (CF1), J1.4, R9.2
CF2: IC1.26 (CF2), J1.3
CF3: IC1.27 (CF3), J1.2
CF4: IC1.28 (CF4), J1.1
GND: C1.1, C2.2, C3.1, C4.2, C5.1, C6.2, C7.1, C8.1, C9.1, C10.1, C11.1, C12.2, C13.2, C14.2, C15.2, CF1.C, IC1.2 (AGND), IC1.12 (AGND), IC1.19 (DGND), IC1.32 (TEST), IC1.36 (DMA_CTRL), IC1.44 (DGND), IC1.47 (DGND), PWR.C, Y1.2 (3), Y1.4 (3); also elsewhere on the board
IA+: CT1.2, CT1-2.2 (TIP), R3.1, R7.2; also elsewhere on the board
IA-: CT1.1, CT1-2.1 (SLEEVE), JP1.2, R3.2; also elsewhere on the board
IAN: C3.2, IC1.4 (I1N), R3.7
IAP: C2.1, IC1.3 (I1P), R3.8
IB+: CT2.2, CT2-2.2 (TIP), R3.3, R8.2; also elsewhere on the board
IB-: CT2.1, CT2-2.1 (SLEEVE), JP2.2, R3.4; also elsewhere on the board
IBN: C5.2, IC1.6 (I2N), R3.5
IBP: C4.1, IC1.5 (I2P), R3.6
IC+: CT3.2, CT3-2.2 (TIP), R4.2, R6.2; also elsewhere on the board
IC-: CT3.1, CT3-2.1 (SLEEVE), JP3.2, R5.2; also elsewhere on the board
ICN: C7.2, IC1.8 (I3N), R5.1
ICP: C6.1, IC1.7 (I3P), R4.1
IRQ0: IC1.30 (IRQ0); also elsewhere on the board
IRQ1: IC1.31 (IRQ1); also elsewhere on the board
MISO: IC1.39 (SDO), R2.2; also elsewhere on the board
MOSI: IC1.40 (SDI), R2.1; also elsewhere on the board
unnamed: JP1.1, R7.1
unnamed: JP2.1, R8.1
unnamed: CF1.A, R9.1
unnamed: JP3.1, R6.1
unnamed: PWR.A, R10.1
OSCI: IC1.20 (OSCI), Y1.1
OSCO: IC1.21 (OSCO), Y1.3 (2)
SCLK: IC1.38 (SCLK), R2.3; also elsewhere on the board
VAN: C15.1, IC1.14 (V1N), IC1.16 (V2N), IC1.18 (V3N); also elsewhere on the board
VAP: C14.1, IC1.13 (V1P), IC1.15 (V2P), IC1.17 (V3P); also elsewhere on the board
VDD: C10.2, C11.2, IC1.1 (AVDD), IC1.33 (PM0), IC1.34 (PM1), IC1.48 (DVDD), R1.1, R2.5, R2.6, R2.7, R2.8, R10.2; also elsewhere on the board
VDD18: C8.2, C9.2, IC1.42 (VDD18), IC1.43 (VDD18)
VREF: C12.1, C13.1, IC1.11 (VREF)
WARN: IC1.29 (WARNOUT); also elsewhere on the board
ZX0: IC1.22 (ZX0), ZX0.1
ZX1: IC1.23 (ZX1), ZX1.1
ZX2: IC1.24 (ZX2), ZX2.1

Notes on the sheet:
ATM30E32
Connections
*Optoisolators should be used if connecting CF outputs
Current Sensing

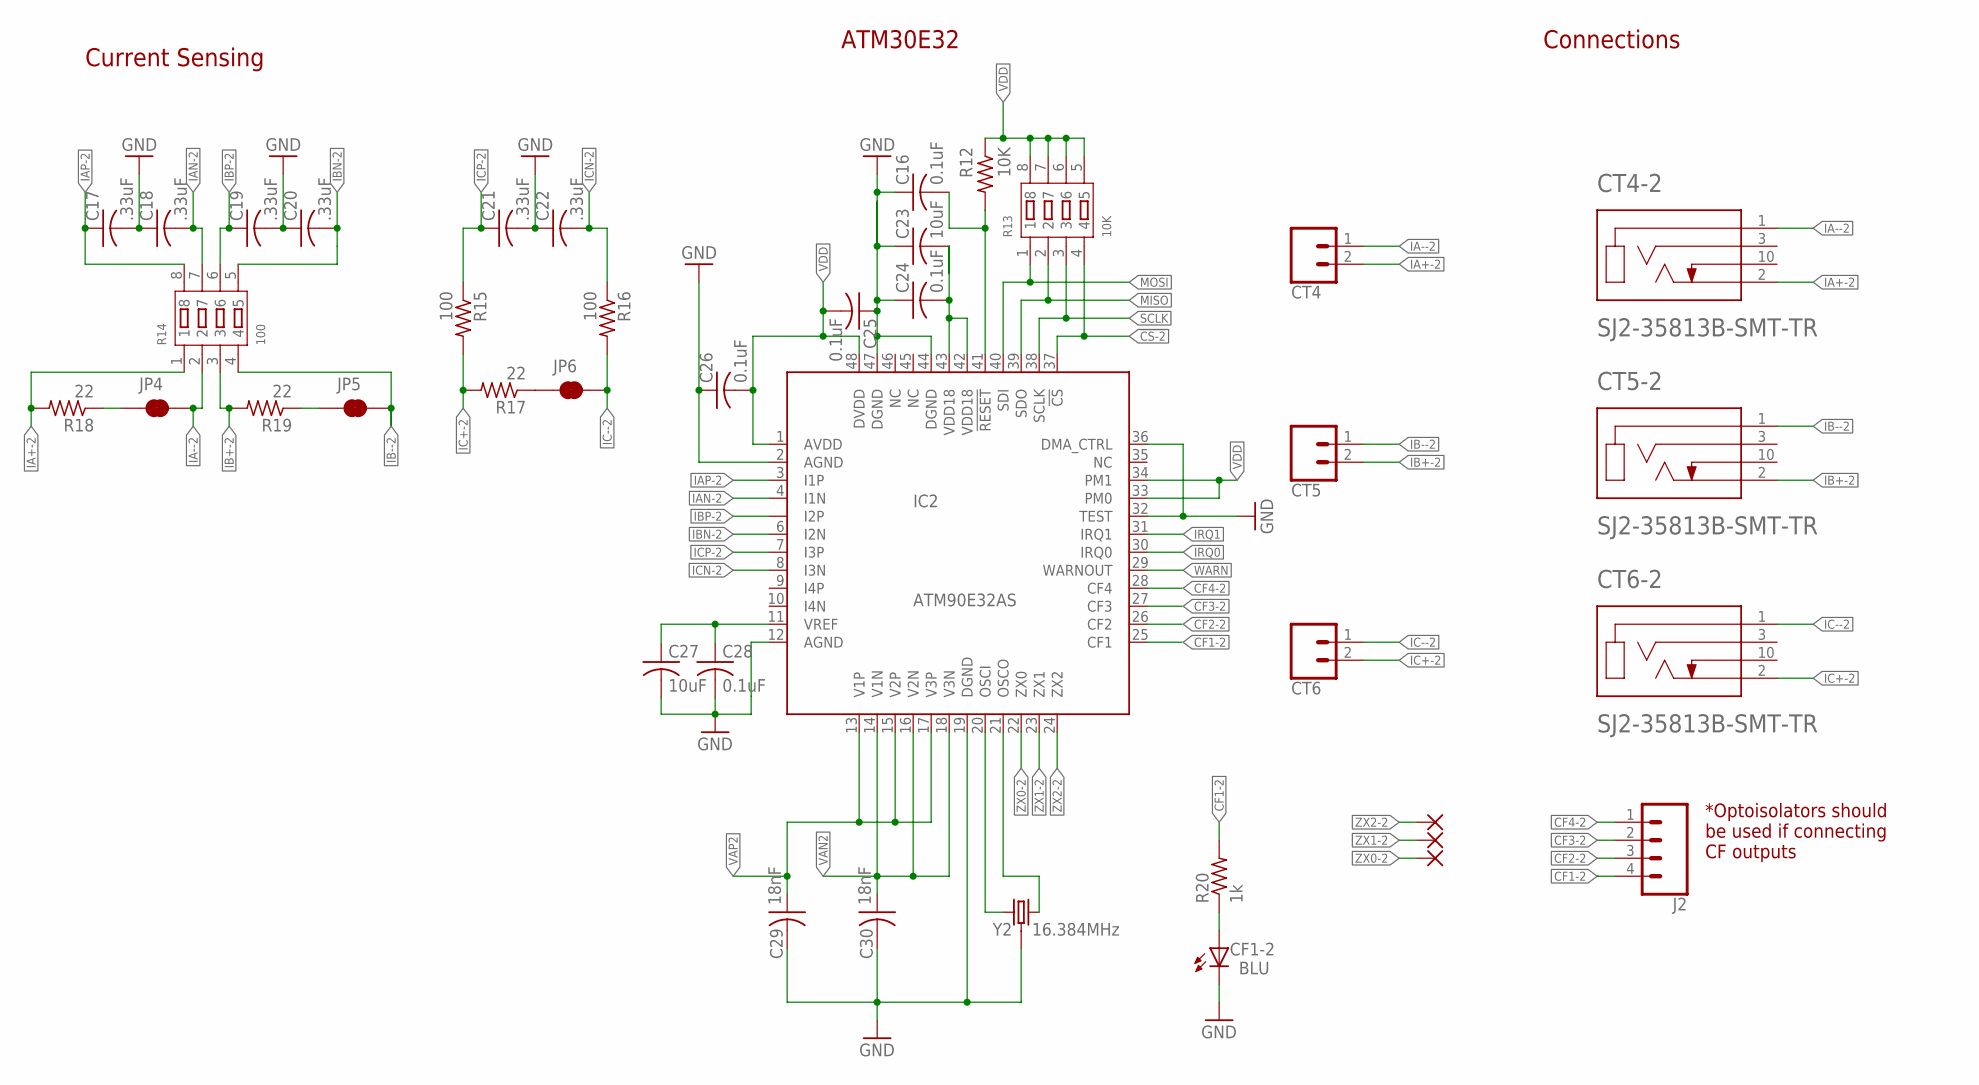
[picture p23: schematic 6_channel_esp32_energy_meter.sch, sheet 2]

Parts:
C16, C24, C25, C26, C28: 0.1uF; C0603
C17, C18, C19, C20, C21, C22: .33uF; C0603
C23, C27: 10uF; C0603
C29, C30: 18nF; C0603
CF1-2: BLU; CHIPLED_0603
CT4, CT5, CT6: CONN_023.5MM; SCREWTERMINAL-3.5MM-2
CT4-2, CT5-2, CT6-2: SJ2-35813B-SMT-TR; CUI_SJ2-35813B-SMT-TR
IC2: ATM90E32AS; QFP50P900X900X120-48
J2: CONN_04; 1X04
JP4, JP5, JP6: JUMPER-SMT_2_NC_TRACE_SILK; SMT-JUMPER_2_NC_TRACE_SILK
R12: 10K; R0603
R13: 10K; RA1206-8
R14: 100; RA1206-8
R15, R16: 100; R0603
R17, R18, R19: 22; R0603
R20: 1k; R0603
Y2: 16.384MHz; CRYSTAL-SMD-3.2X2.5MM
ZX0-2, ZX1-2, ZX2-2: WIREPADSMD1,27-254; SMD1,27-2,54

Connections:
!CS-2: IC2.37 (!CS), R13.4; also elsewhere on the board
!RESET2: C16.2, IC2.41 (!RESET), R12.2
CF1-2: IC2.25 (CF1), J2.4, R20.2
CF2-2: IC2.26 (CF2), J2.3
CF3-2: IC2.27 (CF3), J2.2
CF4-2: IC2.28 (CF4), J2.1
GND: C16.1, C17.2, C18.1, C19.2, C20.1, C21.2, C22.1, C23.1, C24.1, C25.1, C26.1, C27.2, C28.2, C29.2, C30.2, CF1-2.C, IC2.2 (AGND), IC2.12 (AGND), IC2.19 (DGND), IC2.32 (TEST), IC2.36 (DMA_CTRL), IC2.44 (DGND), IC2.47 (DGND), Y2.2 (3), Y2.4 (3); also elsewhere on the board
IA+-2: CT4.2, CT4-2.2 (TIP), R14.1, R18.2; also elsewhere on the board
IA--2: CT4.1, CT4-2.1 (SLEEVE), JP4.2, R14.2; also elsewhere on the board
IAN-2: C18.2, IC2.4 (I1N), R14.7
IAP-2: C17.1, IC2.3 (I1P), R14.8
IB+-2: CT5.2, CT5-2.2 (TIP), R14.3, R19.2; also elsewhere on the board
IB--2: CT5.1, CT5-2.1 (SLEEVE), JP5.2, R14.4; also elsewhere on the board
IBN-2: C20.2, IC2.6 (I2N), R14.5
IBP-2: C19.1, IC2.5 (I2P), R14.6
IC+-2: CT6.2, CT6-2.2 (TIP), R15.2, R17.2; also elsewhere on the board
IC--2: CT6.1, CT6-2.1 (SLEEVE), JP6.2, R16.2; also elsewhere on the board
ICN-2: C22.2, IC2.8 (I3N), R16.1
ICP-2: C21.1, IC2.7 (I3P), R15.1
IRQ0: IC2.30 (IRQ0); also elsewhere on the board
IRQ1: IC2.31 (IRQ1); also elsewhere on the board
MISO: IC2.39 (SDO), R13.2; also elsewhere on the board
MOSI: IC2.40 (SDI), R13.1; also elsewhere on the board
unnamed: JP4.1, R18.1
unnamed: JP5.1, R19.1
unnamed: JP6.1, R17.1
unnamed: CF1-2.A, R20.1
OSCI2: IC2.20 (OSCI), Y2.1
OSCO2: IC2.21 (OSCO), Y2.3 (2)
SCLK: IC2.38 (SCLK), R13.3; also elsewhere on the board
VAN2: C30.1, IC2.14 (V1N), IC2.16 (V2N), IC2.18 (V3N); also elsewhere on the board
VAP2: C29.1, IC2.13 (V1P), IC2.15 (V2P), IC2.17 (V3P); also elsewhere on the board
VDD: C25.2, C26.2, IC2.1 (AVDD), IC2.33 (PM0), IC2.34 (PM1), IC2.48 (DVDD), R12.1, R13.5, R13.6, R13.7, R13.8; also elsewhere on the board
VDD2: C23.2, C24.2, IC2.42 (VDD18), IC2.43 (VDD18)
VREF2: C27.1, C28.1, IC2.11 (VREF)
WARN: IC2.29 (WARNOUT); also elsewhere on the board
ZX0-2: IC2.22 (ZX0), ZX0-2.1
ZX1-2: IC2.23 (ZX1), ZX1-2.1
ZX2-2: IC2.24 (ZX2), ZX2-2.1

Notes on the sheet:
ATM30E32
Connections
*Optoisolators should be used if connecting CF outputs
Current Sensing

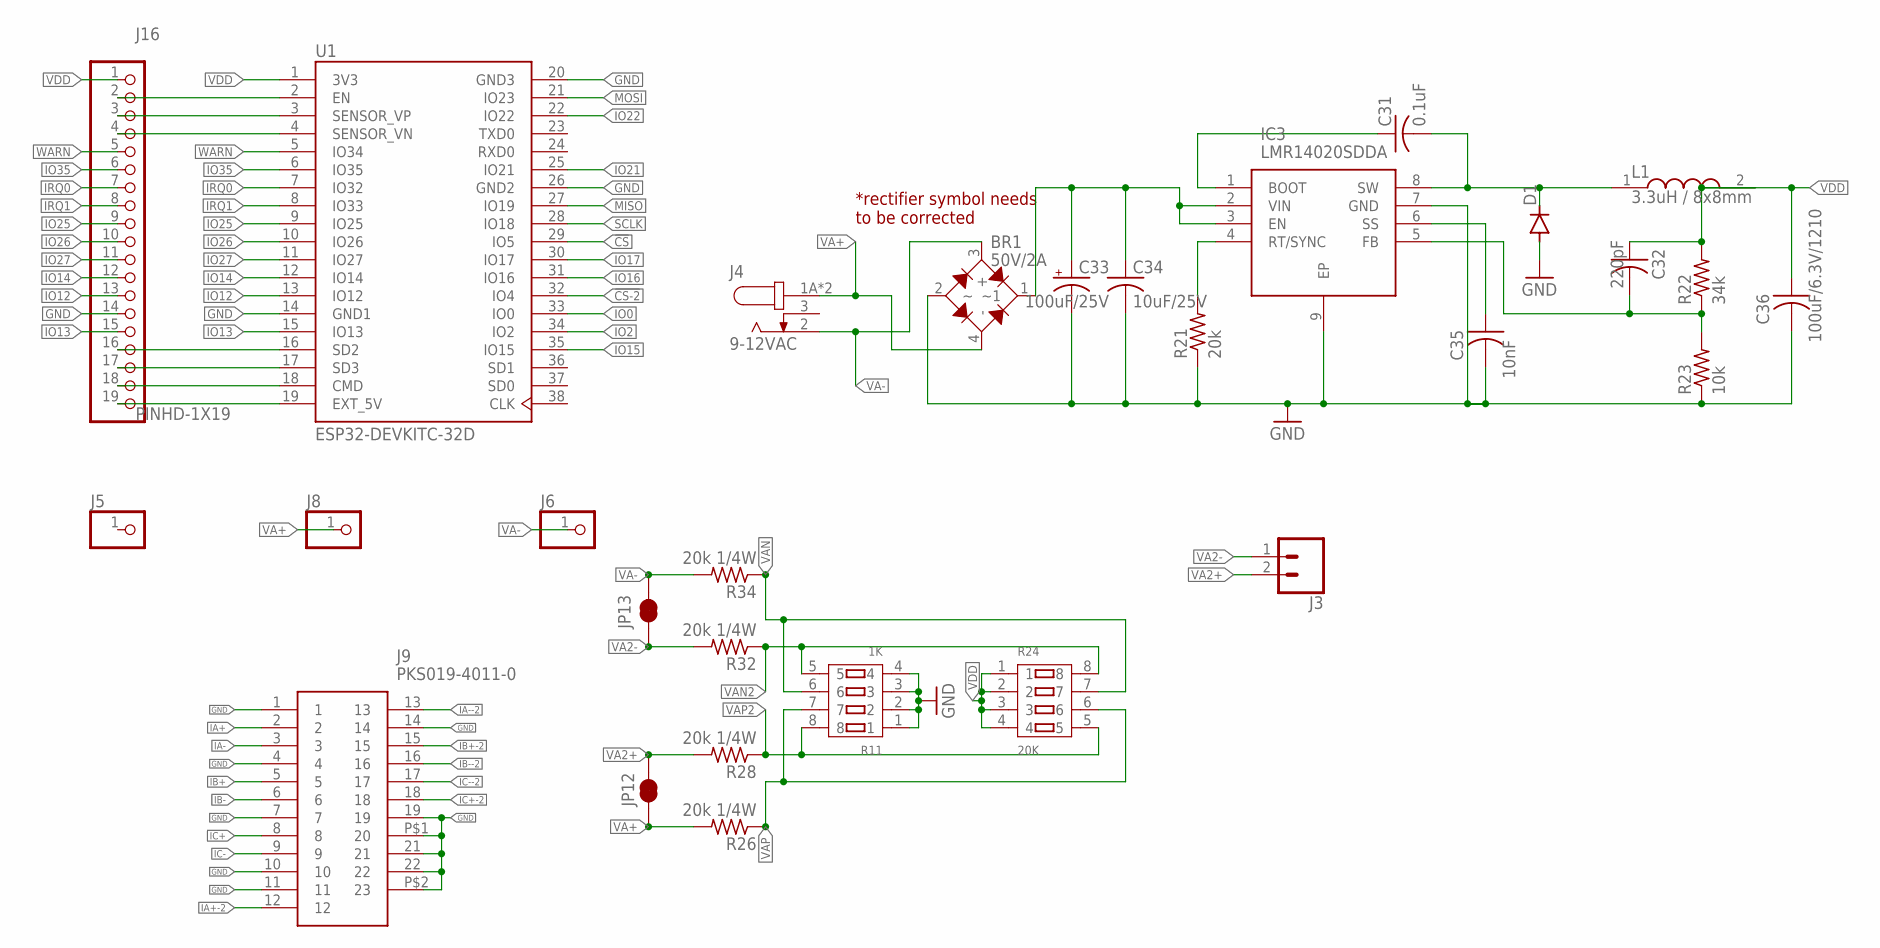
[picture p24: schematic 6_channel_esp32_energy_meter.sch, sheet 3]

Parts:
BR1: 50V/2A; SOP270P700X270-4
C31: 0.1uF; C0603
C32: 220pF; C0603
C33: 100uF/25V; UD-6,3X7,7_NICHICON
C34: 10uF/25V; C0805
C35: 10nF; C0603
C36: 100uF/6.3V/1210; C1210
D1: DIODE-DO214AC; DO214AC
IC3: LMR14020SDDA; SOIC127P600X170-9N
J3: CONN_023.5MM; SCREWTERMINAL-3.5MM-2
J4: 9-12VAC; CUI_PJ-002AH-SMT-TR
J5, J6, J8: PINHD1X1-SM1X01_SM; 1X01-SM
J9: PKS019-4011-0; PKS01940110
J16: PINHD-1X19; 1X19
JP12, JP13: JUMPER-SMT_2_NC_TRACE_SILK; SMT-JUMPER_2_NC_TRACE_SILK
L1: 3.3uH / 8x8mm; INDPM8082X300N
R11: 1K; RA1206-8
R21: 20k; R0603
R22: 34k; R0603
R23: 10k; R0603
R24: 20K; RA1206-8
R26, R28, R32, R34: 20k 1/4W; R0603
U1: ESP32-DEVKITC-32D; MODULE_ESP32-DEVKITC-32D

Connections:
!CS: U1.29 (IO5); also elsewhere on the board
!CS-2: U1.32 (IO4); also elsewhere on the board
BOOT: C31.1, IC3.1 (BOOT)
FB: C32.2, IC3.5 (FB), R22.1, R23.2
GND: BR1.2, C33.-, C34.2, C35.2, C36.2, D1.A, IC3.7 (GND), IC3.9 (EP), J9.1, J9.4, J9.7, J9.10, J9.11, J9.14, J9.19, J9.21, J9.22, J9.P$1 (20), J9.P$2 (23), J16.14, R11.1, R11.2, R11.3, R11.4, R21.1, R23.1, U1.14 (GND1), U1.20 (GND3), U1.26 (GND2); also elsewhere on the board
IA+: J9.2; also elsewhere on the board
IA+-2: J9.12; also elsewhere on the board
IA-: J9.3; also elsewhere on the board
IA--2: J9.13; also elsewhere on the board
IB+: J9.5; also elsewhere on the board
IB+-2: J9.15; also elsewhere on the board
IB-: J9.6; also elsewhere on the board
IB--2: J9.16; also elsewhere on the board
IC+: J9.8; also elsewhere on the board
IC+-2: J9.18; also elsewhere on the board
IC-: J9.9; also elsewhere on the board
IC--2: J9.17; also elsewhere on the board
IO0: U1.33 (IO0)
IO2: U1.34 (IO2)
IO12: J16.13, U1.13 (IO12)
IO13: J16.15, U1.15 (IO13)
IO14: J16.12, U1.12 (IO14)
IO15: U1.35 (IO15)
IO16: U1.31 (IO16)
IO17: U1.30 (IO17)
IO21: U1.25 (IO21)
IO22: U1.22 (IO22)
IO25: J16.9, U1.9 (IO25)
IO26: J16.10, U1.10 (IO26)
IO27: J16.11, U1.11 (IO27)
IO35: J16.6, U1.6 (IO35)
IRQ0: J16.7, U1.7 (IO32); also elsewhere on the board
IRQ1: J16.8, U1.8 (IO33); also elsewhere on the board
MISO: U1.27 (IO19); also elsewhere on the board
MOSI: U1.21 (IO23); also elsewhere on the board
unnamed: J16.2, U1.2 (EN)
unnamed: J16.3, U1.3 (SENSOR_VP)
unnamed: J16.4, U1.4 (SENSOR_VN)
unnamed: J16.16, U1.16 (SD2)
unnamed: J16.17, U1.17 (SD3)
unnamed: J16.18, U1.18 (CMD)
unnamed: J16.19, U1.19 (EXT_5V)
RT: IC3.4 (RT/SYNC), R21.2
SCLK: U1.28 (IO18); also elsewhere on the board
SS: C35.1, IC3.6 (SS)
SW: C31.2, D1.C, IC3.8 (SW), L1.1
VA2+: J3.2, JP12.1, R28.2
VA2-: J3.1, JP13.1, R32.2
VA+: BR1.4 (-), J4.1A (1), J4.1B (1), J8.1, JP12.2, R26.2
VA-: BR1.3 (+), J4.2, J6.1, JP13.2, R34.2
VAN: R11.6, R24.7, R34.1; also elsewhere on the board
VAN2: R11.5, R24.8, R32.1; also elsewhere on the board
VAP: R11.7, R24.6, R26.1; also elsewhere on the board
VAP2: R11.8, R24.5, R28.1; also elsewhere on the board
VDD: C32.1, C36.1, J16.1, L1.2, R22.2, R24.1, R24.2, R24.3, R24.4, U1.1 (3V3); also elsewhere on the board
VIN: BR1.1 (~1), C33.+, C34.1, IC3.2 (VIN), IC3.3 (EN)
WARN: J16.5, U1.5 (IO34); also elsewhere on the board

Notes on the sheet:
*rectifier symbol needs to be corrected

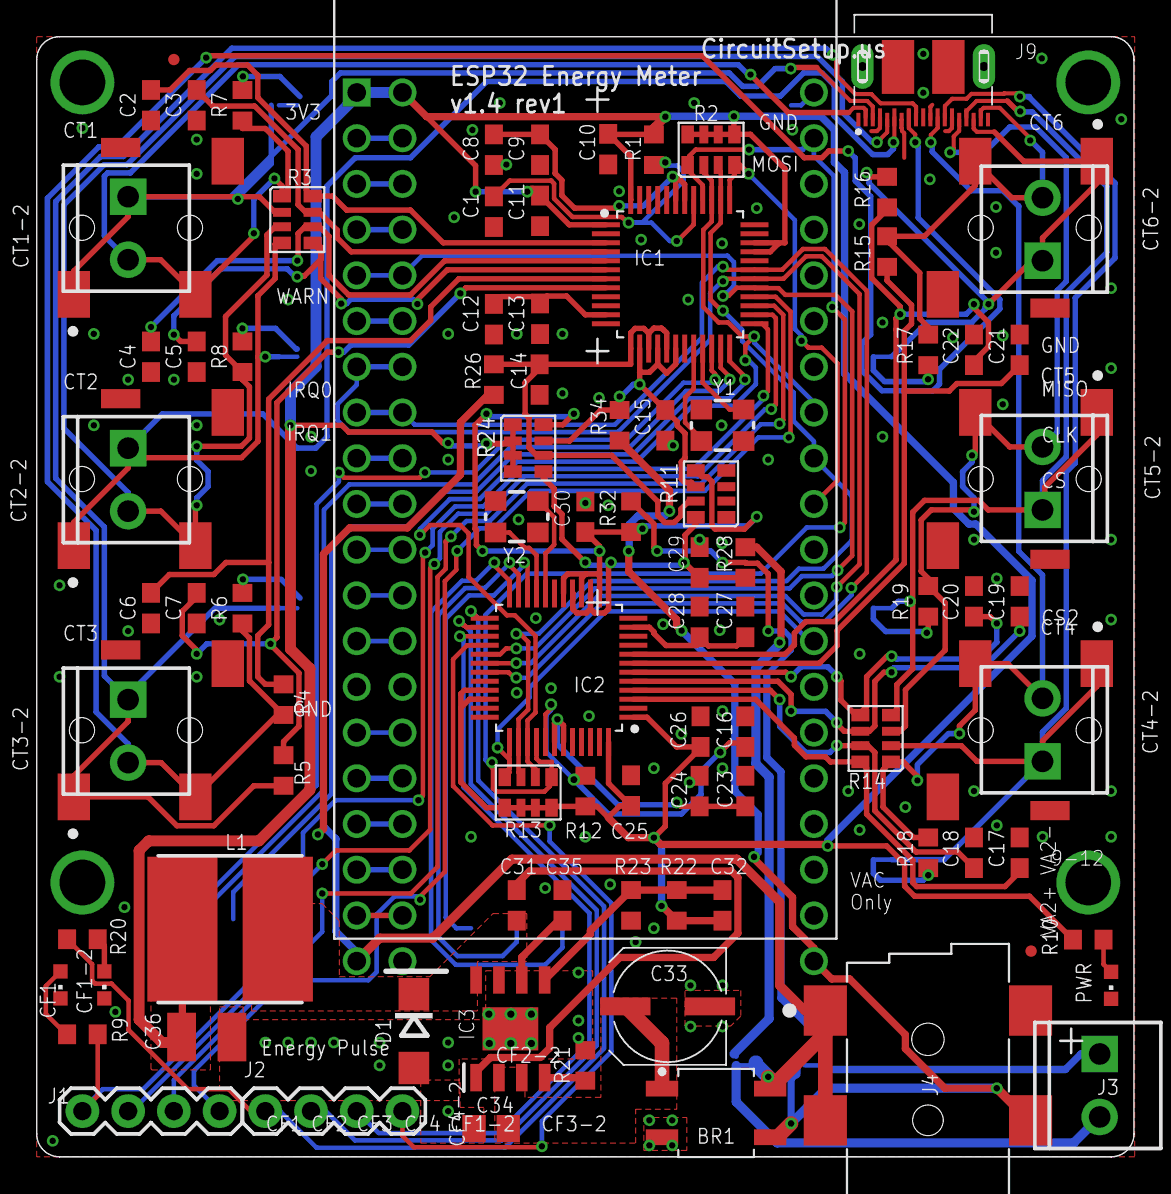
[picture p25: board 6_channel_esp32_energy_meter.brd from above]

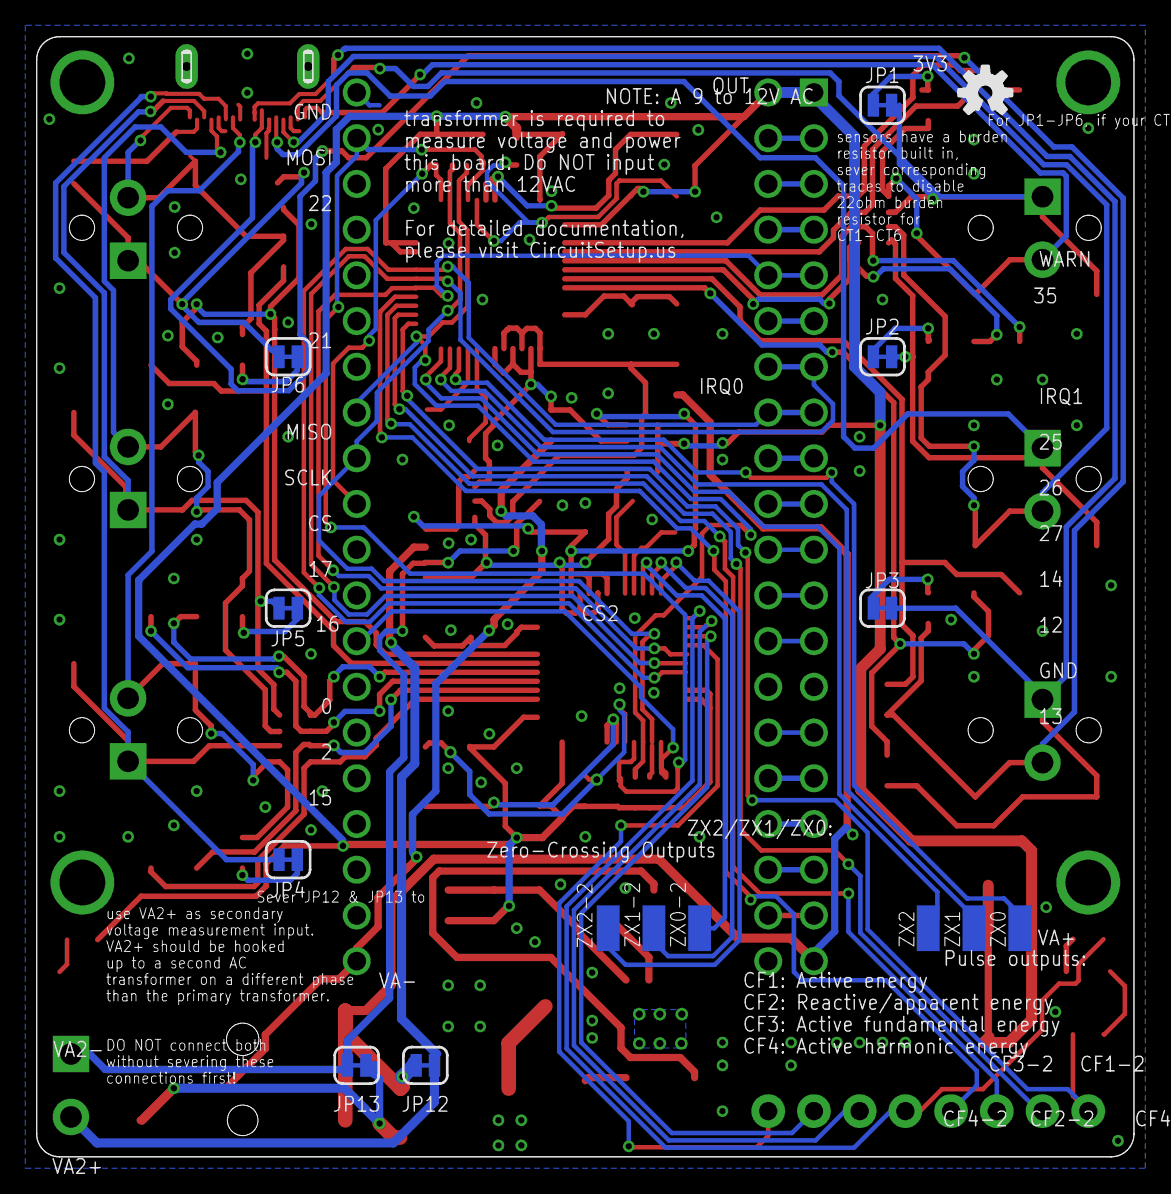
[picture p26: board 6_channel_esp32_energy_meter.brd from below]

Board: 2 copper layers, 61.0 x 62.2 mm, 114 parts (15 on the bottom side), 95 nets.

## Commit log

2020-08-23 Convert to kicad.
    [6_channel_esp32_energy_meter.brd, 6_channel_esp32_energy_meter.kicad_pcb, 6_channel_esp32_energy_meter.sch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]
2020-08-23 Make the schematic not terrible.
    [6_channel_esp32_energy_meter.kicad_pcb, 6_channel_esp32_energy_meter.sch, 6_channel_esp32_energy_meter_1.sch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]
2020-08-23 Working on layout.
    [6_channel_esp32_energy_meter.kicad_pcb, 6_channel_esp32_energy_meter.sch, single_metering_ic.sch]
2020-08-24 Minor footprint cleanup.
    [6_channel_esp32_energy_meter.kicad_pcb, 6_channel_esp32_energy_meter.sch, single_metering_ic.sch]
2020-08-24 Project cleanup. Kicad has too many garbage files it sprays everywhere.
    [Energy Monitor - Sensor PCB.kicad_pcb, Energy Monitor - Sensor PCB.sch, single_metering_ic.sch]
2020-08-25 Transformer PCB.
    [Energy Monitor - Transformer PCB.kicad_pcb, Energy Monitor - Transformer PCB.sch]
2020-08-25 Interface board.
    [EnergyMonitor - ESP PCB.kicad_pcb, EnergyMonitor - ESP PCB.sch]
2020-08-26 This seems to be getting progressively more complicated. Library cleanup, moved everything to my system library.
    [Energy Monitor - Sensor PCB.kicad_pcb, Energy Monitor - Sensor PCB.sch, Energy Monitor - Transformer PCB.kicad_pcb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]
2020-08-29 Updates! I keep adding features.
    [ESP32 and Comms.sch, Energy Monitor - Sensor PCB.kicad_pcb, EnergyMonitor - ESP PCB.kicad_pcb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]
2020-08-30 Bus-based board variant.
    [Energy Monitor - Sensor PCB.kicad_pcb, Energy Monitor - Sensor PCB.sch, single_metering_ic.sch]
2020-08-31 Common-bus variant of the power monitor.
    [ESP32 and Comms.sch, Energy Monitor - ESP32 PCB - Bussed.kicad_pcb, Energy Monitor - ESP32 PCB - Bussed.sch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]
2020-09-06 Switch to a better jack.
    [Energy Monitor - Sensor PCB.kicad_pcb, Energy Monitor - Sensor PCB.sch, single_metering_ic.sch]

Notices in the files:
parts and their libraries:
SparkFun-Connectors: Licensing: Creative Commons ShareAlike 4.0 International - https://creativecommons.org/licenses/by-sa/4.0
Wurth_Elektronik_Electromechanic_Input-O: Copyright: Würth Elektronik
